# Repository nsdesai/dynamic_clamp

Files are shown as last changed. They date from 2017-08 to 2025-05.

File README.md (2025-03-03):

# dynamic_clamp
A fast, microcontroller-based dynamic clamp system

The system was introduced in this paper: Niraj S. Desai, Richard Gray, and Daniel Johnston. A dynamic clamp on every rig. eNeuro (DOI:10.1523/ENEURO.0250-17.2017).

The website https://optogeneticsandneuralengineeringcore.gitlab.io/dynamicclampsite/ includes detailed instructions on how to assemble and use the system. It includes descriptions of recent updates.

This site (github.com) houses most of the associated software (Arduino, Processing, Matlab).

The original project was built on a breadboard and used Arduino/Processing software. Some alternatives you might consider:

(1) Leo and Manuel Covarrubias have further developed the design and created a different printed circuit board (PCB) version. Called Open Dynamic Clamp (ODC) it includes numerous improvements that will, hopefully, "future proof" the project. Information about ODC is contained here: https://github.com/nsdesai/dynamic_clamp/tree/master/open-dynamic-clamp.

(2) Aditya Asopa (https://github.com/AdityaAsopa) has designed a PCB version that can be used in place of the breadboard. It includes some nice additional features, including a toggle switch to bypass the dynamic clamp circuitry (useful if one wants to just work in current clamp). The design files are in the Circuit_and_PCB folder, while a setup and calibration manual is in the Setup_and_Calibration folder.

(3) Christian Rickert has written alternative software (dyClamp and pyClamp) with extended functionality, including a Python-based control GUI. His software is described at https://dynamicclamp.com/python-alternative/ and is available through his Github account https://github.com/christianrickert.

(4) Kyle Wedgwood has written a Matlab controller that would replace the Processing sketch included here. It allows more flexibility in specifying which conductances to control, and is available through his Github account https://github.com/kyle-wedgwood/DynamicClampController.

Please direct any questions or comments about this Github site or the dynamic clamp project generally to Niraj S. Desai at niraj.s.desai@gmail.com.

******************************************************************************************************************************************
Permission is hereby granted, free of charge, to any person obtaining a copy of this software and associated documentation files (the "Software"), to deal in the Software without restriction, including without limitation the rights to use, copy, modify, merge, publish, distribute, sublicense, and/or sell copies of the Software, and to permit persons to whom the Software is furnished to do so, subject to the following conditions:

The above copyright notice and this permission notice shall be included in all copies or substantial portions of the Software.

THE SOFTWARE IS PROVIDED "AS IS", WITHOUT WARRANTY OF ANY KIND, EXPRESS OR IMPLIED, INCLUDING BUT NOT LIMITED TO THE WARRANTIES OF MERCHANTABILITY, FITNESS FOR A PARTICULAR PURPOSE AND NONINFRINGEMENT. IN NO EVENT SHALL THE AUTHORS OR COPYRIGHT HOLDERS BE LIABLE FOR ANY CLAIM, DAMAGES OR OTHER LIABILITY, WHETHER IN AN ACTION OF CONTRACT, TORT OR OTHERWISE, ARISING FROM, OUT OF OR IN CONNECTION WITH THE SOFTWARE OR THE USE OR OTHER DEALINGS IN THE SOFTWARE.

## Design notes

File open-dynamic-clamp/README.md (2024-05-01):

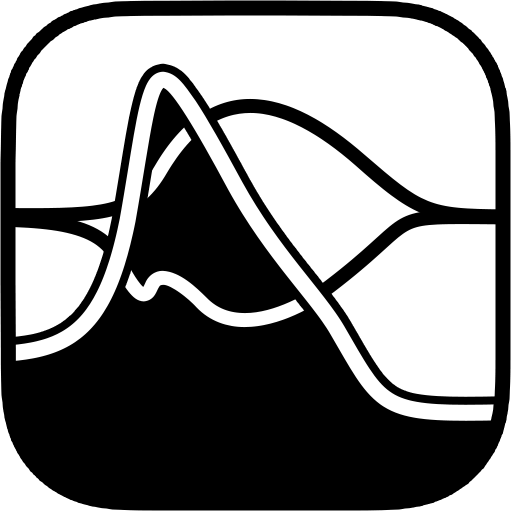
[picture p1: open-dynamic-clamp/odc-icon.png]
#  Open Dynamic Clamp

The Open Dynamic Clamp project (abbreviated ODC) is an extension of the the work by [Niraj Desai](https://github.com/nsdesai), [Aditya Asopa](https://github.com/AdityaAsopa), and other contributors.
It aims to provide consistent, incremental progress on dynamic clamp hardware and software for the scientific community by documenting manufacturable designs that
lower the barrier for use by any interested researchers.

- Hardware is licensed under [CC BY 4.0](https://creativecommons.org/licenses/by/4.0/) terms.



# Versions

- [ODC 1.0](odc-1.0/prototype.md)
  - Hand-built prototype design
- [ODC 1.2](odc-1.2/README.md)
  - PCB hardware and 3D Printed Enclosure

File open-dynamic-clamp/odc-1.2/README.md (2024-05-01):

# Open Dynamic Clamp 1.2

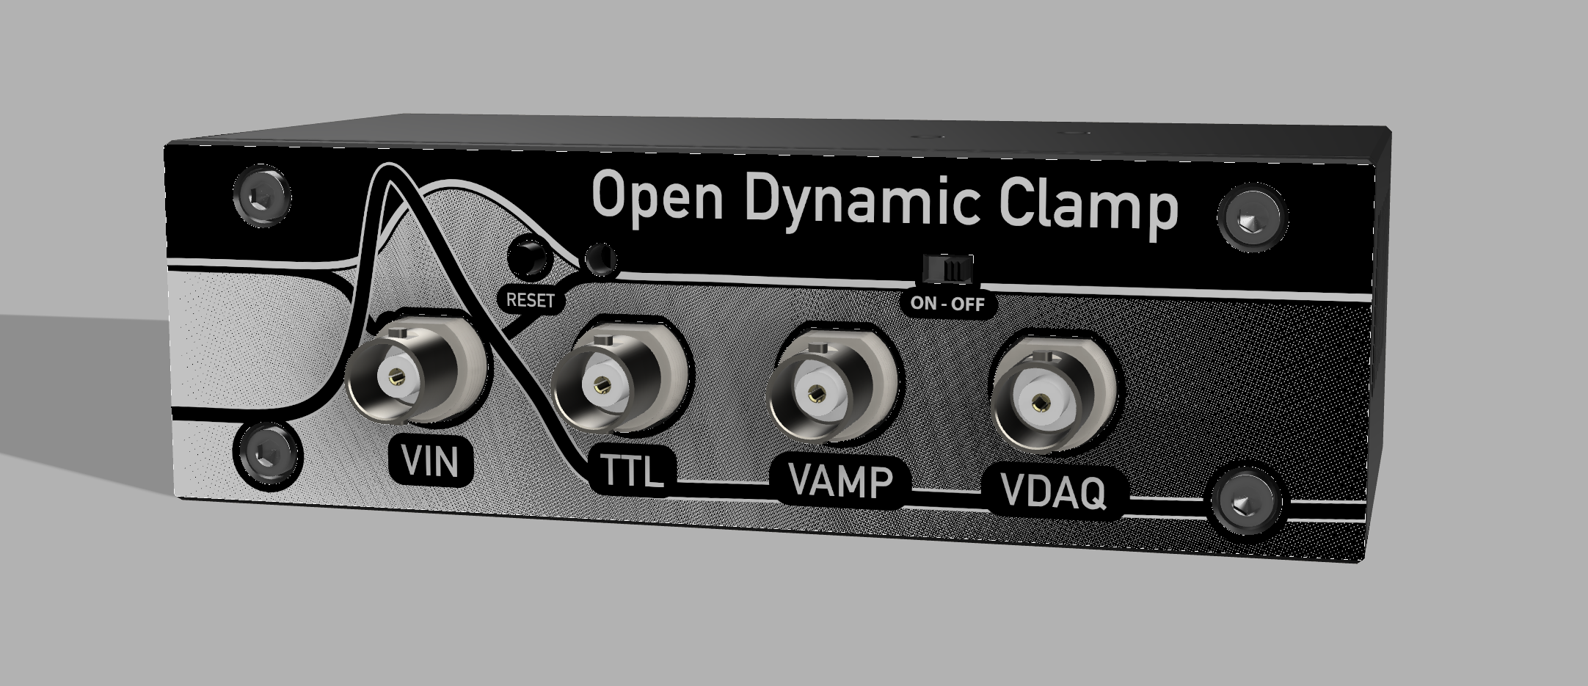
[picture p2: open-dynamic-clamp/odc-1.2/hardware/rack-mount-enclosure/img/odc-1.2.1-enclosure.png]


### Notable Features
- 100% compatible with existing Arduino firmware
- Using the [Adafruit ItsyBitsy M4](https://learn.adafruit.com/introducing-adafruit-itsybitsy-m4) microcontroller (SAMD51 MCU)
- Simplified power circuitry
  - USB used to source all power, no additional DC input required
  - 3.3V sourced from the ItsyBitsy's built-in voltage regulator
  - Op amp dual rail provided by 5V to +/-12V DC-to-DC module
- TLE2142 Op amp replaces LM358 for improved signal quality
- Trim potentiometers for Op amp gain and offset adjustment
- Expansion port for additional ADC inputs
- Tag-Connect Plug-of-Nails debugging header
- Fully specified BOM with the highest quality components

### Project Files

- [Hardware PCB Guide](./hardware/README.md)
  - KiCad Project
- [3D Printed Enclosure Guide](./hardware/rack-mount-enclosure/README.md)
  - STL Files
  - Faceplate Graphic

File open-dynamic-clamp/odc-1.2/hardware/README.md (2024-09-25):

# Open Dynamic Clamp 1.2 Hardware

This documentation describes circuit schematics for the ODC 1.2 hardware iteration.
This design is based on the work of [Aditya Asopa's updated schematic](../../../Setup%20and%20Calibration%20Manual%20for%20ver2.0/Setup%20Manual.pdf).

This hardware design is licensed under [CC BY 4.0](https://creativecommons.org/licenses/by/4.0/).

- Table of Contents
  - [User Guide](#user-guide)
  - [PCB Assembly Notes](#pcb-assembly-notes)
  - [Calibration Notes](#calibration-notes)
  - [Firmware Notes](#firmware-notes)

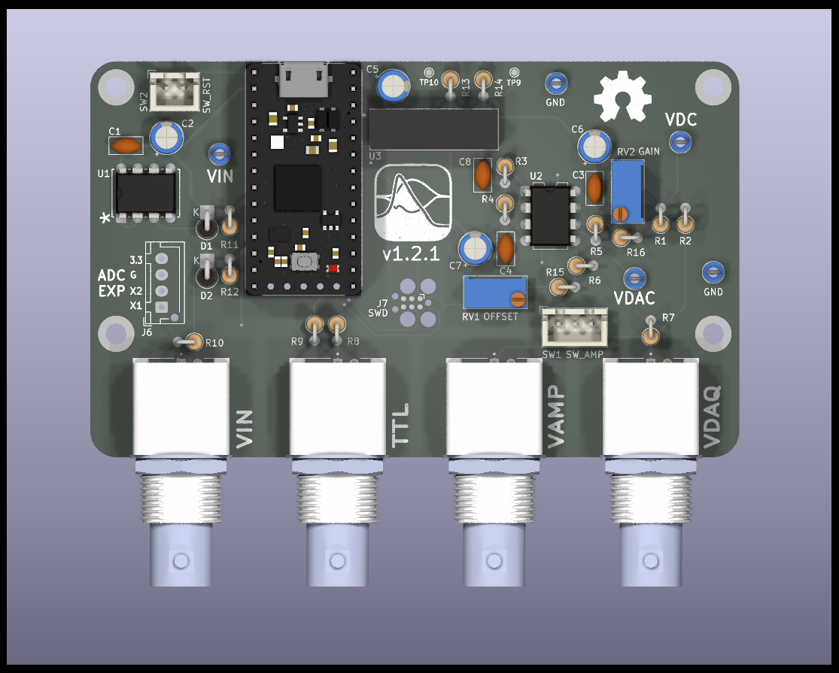
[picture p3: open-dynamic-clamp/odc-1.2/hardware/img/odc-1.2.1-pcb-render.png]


# User Guide

The design may be built successfully on a breadboard or ordered as a PCB.

- [KiCad Project](./odc-1.2)
  - [Schematic](./odc-1.2/pdf/odc-1.2.pdf)
  - [BOM](./odc-1.2/bom/odc-1.2-bom.csv)
  - [Fabrication](./odc-1.2/gerber/README.md)
- The design has been created with 100x amplification in mind
- Choose resistors with a low tolerance to avoid calibration problems (the BOM specifies high quality resistors)
  - 0.1% resistors are highly recommended but 1% resistors may be acceptable with calibration.
  - [DigiKey importable cart CSV](odc-1.2/bom/odc-1.2-digikey-cart.csv) is available with all components pre-configured.
- Double check connections before powering the circuit from the ItsyBitsy M4 module.
  - A short circuit has the risk of burning out the microcontroller module's on-board regulator.
  - Testing with the ItsyBitsy board connected by jumper wires is encouraged.
- The ADC EXP expansion port is NOT protected from over-voltage. The ItsyBitsy M4 will be damaged by voltages outside the 0-3.3V range.
- The trim potentiometers should be tuned during calibration.
- If mounting in a 3d printed enclosure the two switches should be extended from the PCB with short wire leads. These extension wires may be soldered directly to the pcb or made detachable using JST XH connectors.

# PCB Assembly Notes

An [interactive BOM](odc-1.2/bom/ibom.html) is available to help with assembly (open the html file in any browser).

- Take careful note of capacitor polarity. 
  - Capacitor C7 is on a negative rail.
- The PCB has a large ground plane that soaks up heat making soldering ground connections tricky.
  - For each component solder the signal or power connection first to hold it in place before carefully soldering the ground.
  - Use plenty of flux. This will significantly improve the solders ability to flow.
    - ChipQuick No-Clean Tack Flux Syringe is highly recommended.
  - Use caution around sensitive components or plastic connectors that might melt.
- Diodes with a "K" on the board are "cathode up" which means the body of the diode lines up with the circular outline and the white stripe is pointing up.
- Use of standard height headers/pins are assumed for the Adafruit ItsyBitsy M4.
  - If you use different height headers the board may not line up with the enclosure opening
  - The 5 bottom middle pins of the ItsyBitsy M4 are only required if using SWD debugging.
- The external reset switch (SW2) is optional. The reset button on the ItsyBitsy M4 board serves the same function.
- The selector switch footprint (SW1) fits any SPDT switch or header with a 2.54mm lead spacing.
- The named test points do not need to be populated but are a convenience for clipping oscilloscope leads calibration/validation.

# Calibration Notes

A validation and calibration process is described in the [Setup Manual](../../../Setup%20and%20Calibration%20Manual%20for%20ver2.0/Setup%20Manual.pdf) by Aditya Asopa.

- Trim potentiometers for `RV1` and `RV2` will aid in setting the gain and offset. There are 2 options.
  1. You may adjust them to produce a symmetrical +/- 3.3V at `VAMP` using [this arduino sketch](./scripts/trim-gain-and-offset/trim-gain-and-offset.ino) and an oscilloscope (Must have `VDAQ` at 0V).
  2. You may adjust them to produce the exact same output as described in validation Table 2 (page 13) and Table 3 (page 15).
- To provide the required `5V` and `3.3V` power rails during initial validation you may:
  - provide the correct voltages to the correct header pins with the ItsyBitsy completely removed.
  - Power the ItsyBitsy with a USB cable and connect the `USB`, `3V` and `G` pins to the PCB headers with extension jumpers such that all other pins remain disconnected.
  - Power the ItsyBitsy with a USB cable and socket it into the PCB headers but double-click the reset button to put it into programming mode (this prevents any output voltage on the DAC pin due to any currently loaded firmware). You will see the red LED next to the reset button pulse slowly.
- Calibration to derive the slope and intercept values in table 13 (page 31) required by the firmware may be done by any of the described methods (Direct page 20, Model Cell + Processing page 23, Model Cell + Arduino page 29)
  - If you have hardware conforming to the 1.2.1 design with the trim potentiometers set to produce +/- 3.3V, then these precalculated values should work
    - input slope: `4.9756`
    - input intercept: `-10087.453`
    - output slope: `-624.3895`
    - output intercept: `2108.4`
  - See [example calculations spreadsheet](https://docs.google.com/spreadsheets/d/1fMq_oq5LJLbKDHQDHSRb5kDalZ01myzjR7bMcWg4iwA) for details on deriving calibration values

# Firmware Notes

This hardware revision (ODC 1.2) is 100% compatible with the original
[dynamic_clamp](../../../dynamic_clamp) Arduino firmware.

Adafruit provides an extensive Arduino setup guide which is a prerequisite for loading the firmware.
1. [Setup the Arduino IDE](https://learn.adafruit.com/introducing-adafruit-itsybitsy-m4/setup)
2. [Install Adafruit board support](https://learn.adafruit.com/introducing-adafruit-itsybitsy-m4/using-with-arduino-ide)

> [!IMPORTANT]
> 
> If you are having problems uploading firmware in the Arduino IDE you may need
> to put the device into "Boot Mode" by quickly double-clicking the reset button.
> This is useful if you can't see the device serial port in the Arduino IDE
> board selection window. This should allow you to upload new firmware in cases 
> were bad firmware is crashing the microcontroller.

Additional useful information on the ItsyBitsy M4 board:
- [General board overview](https://learn.adafruit.com/introducing-adafruit-itsybitsy-m4/overview)
- [Board pin descriptions](https://learn.adafruit.com/introducing-adafruit-itsybitsy-m4/pinouts)

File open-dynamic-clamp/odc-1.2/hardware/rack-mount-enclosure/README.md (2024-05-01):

# 3D Printed Enclosure Guide

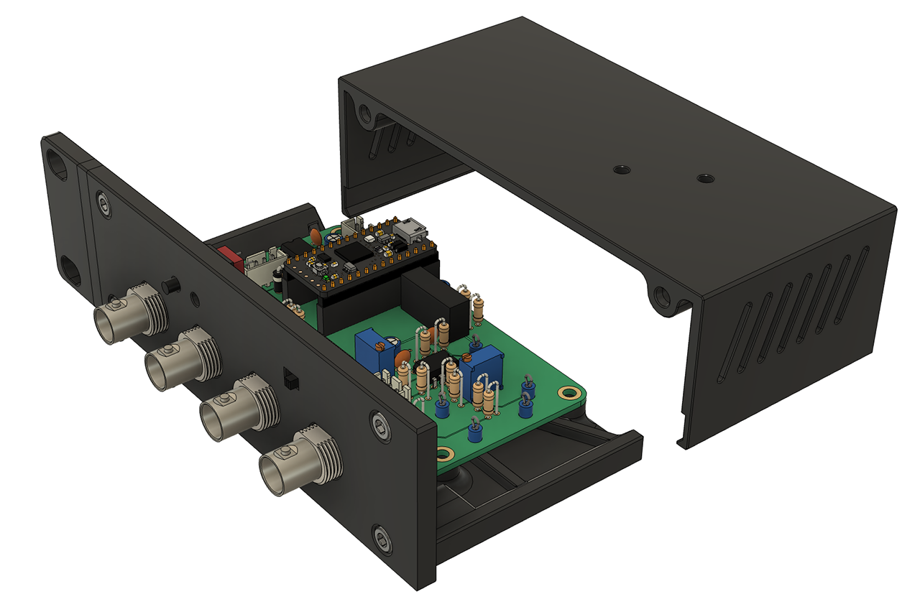
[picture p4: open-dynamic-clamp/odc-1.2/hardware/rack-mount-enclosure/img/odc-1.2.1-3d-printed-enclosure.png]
enclosure-render


For printing a rack mount or desktop enclosure the following files are used.
There are various options for face-plates.

#### STL Files
- Faceplate options (choose one)
  - faceplate-ears-left.stl (rack mount holes on left)
  - faceplate-ears-right.stl (rack mount holes on right)
  - faceplate-no-ears.stl (desktop use, no mounting holes)
- pcb_sled.stl (pcb mounting bracket)
- cover.stl (enclosure cover)

### Fusion 360 Files
A Fusion 360 project (.f3z) is provided for anyone looking to make modifications to the design.

#### Hardware
- 8 M3 heat-set inserts
- 8 M3 6mm bolts

## 3D Printing Notes

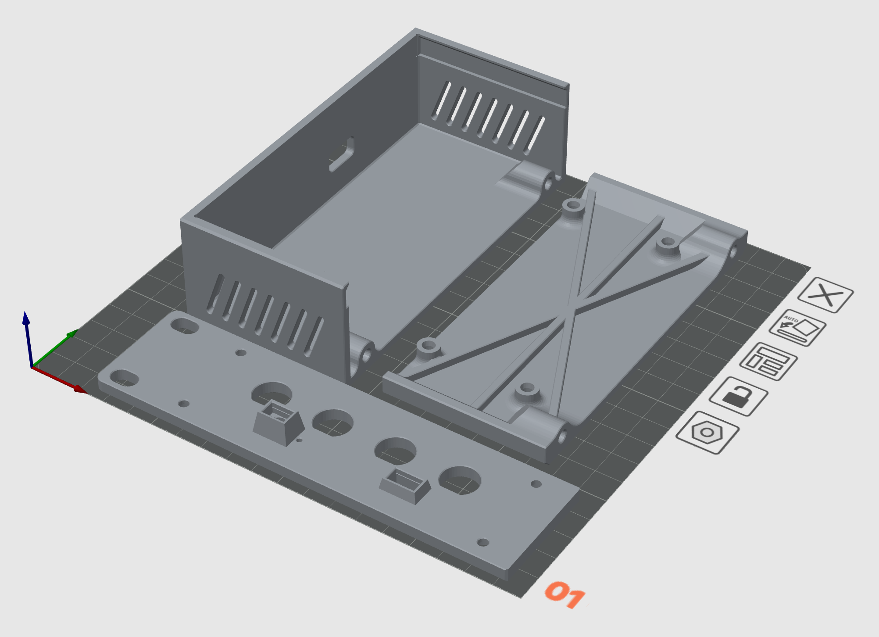
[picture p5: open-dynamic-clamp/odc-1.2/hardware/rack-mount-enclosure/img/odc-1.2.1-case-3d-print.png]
3d-print-build-plate


- All parts will fit together on a 200x200 build plate
- Slicer recommendations
  - PLA filament
  - 0.3 layer height
  - No supports or supports only for usb cable opening

## Faceplate Graphic Notes

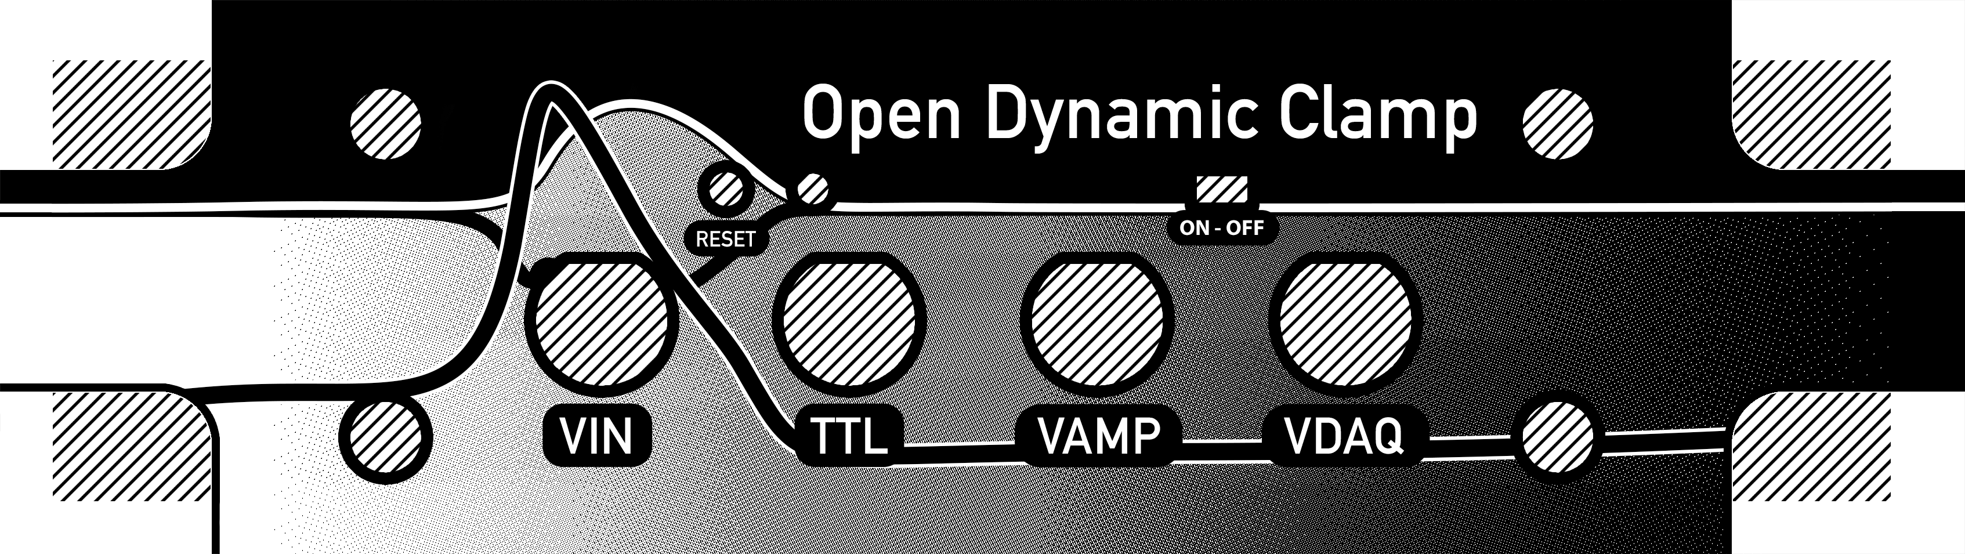
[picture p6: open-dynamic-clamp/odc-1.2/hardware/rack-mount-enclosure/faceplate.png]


Graphic is designed to be printed on a B&W laser printer using Avery 5526 shipping labels.

- Cut out the cross-hatched areas carefully with a new exacto blade.
- Some overlap on edges to be cut has been designed into the graphic so that cuts always happen on black which blends with black 3d printing filament.

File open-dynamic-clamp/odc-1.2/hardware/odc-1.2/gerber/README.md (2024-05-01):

# Fabrication Notes

The gerber files provided are all that's needed for fabrication by a 3rd party PCB manufacturer.

Follow the manufacturers instructions to upload the files from the `odc-1.2/gerber` directory.

The fabrication options conform to most PCB fab capabilities.
There are no special manufacturing requirements.

- 100x61mm size
- 2 layer board
- FR-4
  - 1.6mm
  - TG 130-140 or TG 150-160
- 6/6mil track width/spacing
- 0.3mm min hole size
- 1oz CU

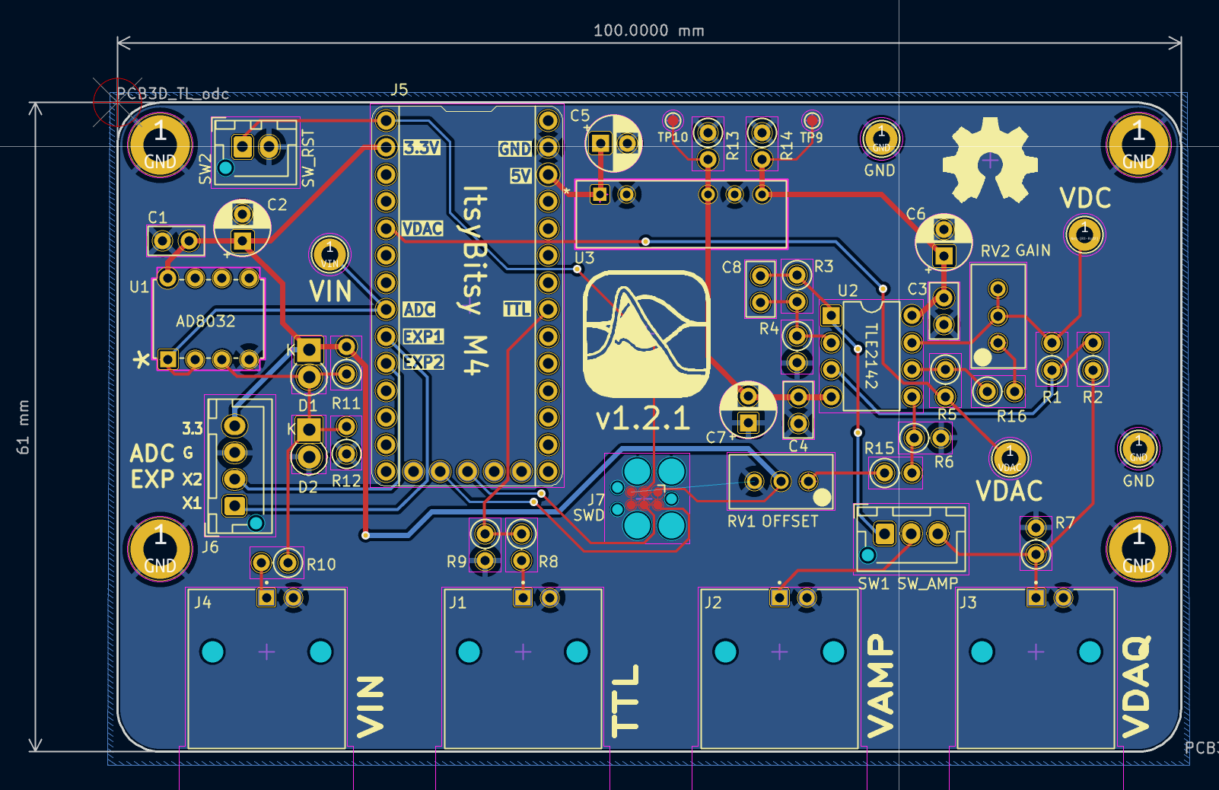
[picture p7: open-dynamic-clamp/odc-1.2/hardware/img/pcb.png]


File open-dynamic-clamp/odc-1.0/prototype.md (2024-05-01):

# Prototype Notes

A single prototype version (considered ODC 1.0) was constructed on proto-board and hand soldered with jumper wires. 
This revision was used by the [Covarrubias Lab, Dep. of Neuroscience at Thomas Jefferson University](https://research.jefferson.edu/labs/researcher/covarrubias-laboratory.html).

### Differences to ODC 1.2

- The prototype was constructed with an LM358 OpAmp for the output signal. Version 1.2 recommends the pin-compatible TLE2142 OpAmp an included an additional filtering capacitor to reduce ringing artifacts.
- The prototype used an external 3.3V regulator instead of the ItsyBitsy's onboard 3.3V regulator.
- Additional bypass capacitors for the voltage rails are not present in the prototype.
- The tolerance of resistor components (5-10%) on the prototype necessitated additional calibration.
- The configuration of the trim potentiometers to adjust output signal offset and gain has been changed to improve stability from thermal variance.
- Proto-board construction (this has not shown a measurable difference compared to the
PCB version).
- Additional pins from the ItsyBitsy are exposed on user accessible headers for ADC inputs and SWD Debugging.
- The BNC ports are not in the same physical order (irrelevant)

### Build Images
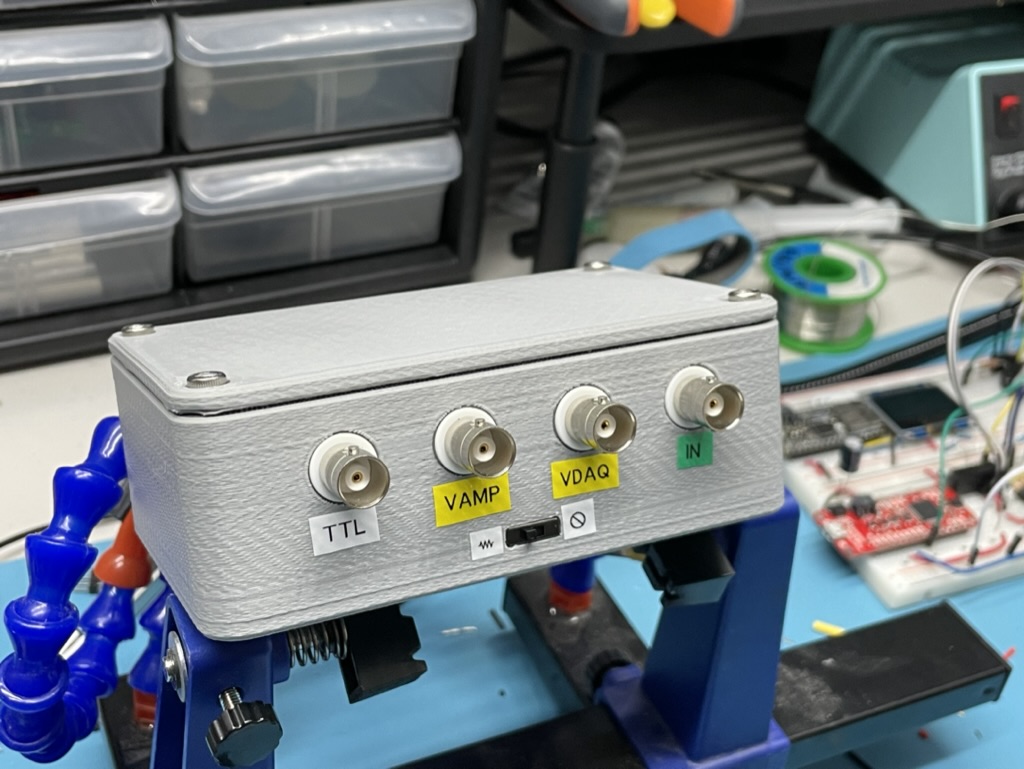
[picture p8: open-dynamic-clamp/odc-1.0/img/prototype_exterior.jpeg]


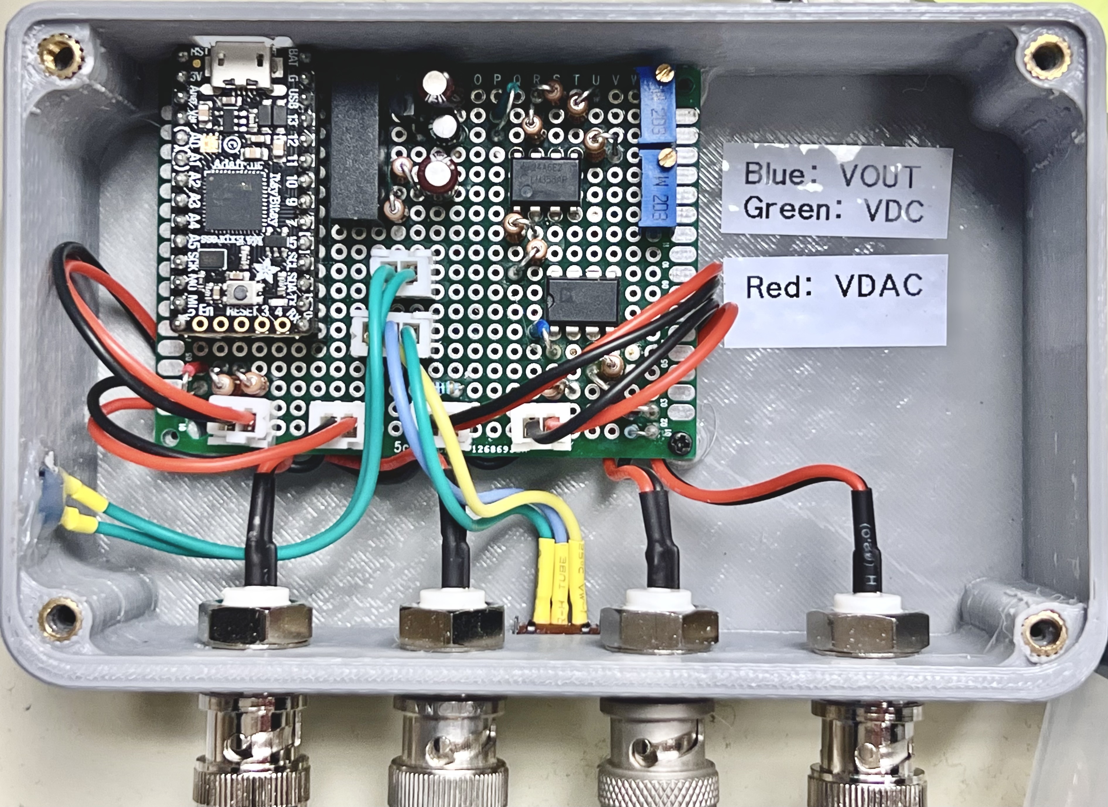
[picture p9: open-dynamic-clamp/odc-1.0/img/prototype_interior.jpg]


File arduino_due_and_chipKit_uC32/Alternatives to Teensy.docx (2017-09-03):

Alternatives to Teensy

We built the dynamic clamp system around the Teensy 3.6 microcontroller because, compared to alternatives of its class and price point, it is faster and has more memory. However, it is important to note that other microcontrollers could be used in its place. In particular, microcontrollers that can be programmed using the Arduino integrated development environment (IDE) require only small modifications to the code. There are many microcontrollers like this because Arduino has emerged as a standard in the community.

To demonstrate this point, we describe in this document how to use an Arduino Due or a chipKit uC32 in place of the Teensy 3.6. Neither is the equal of the Teensy 3.6 in speed or memory, but both are plausible alternatives.

I. Arduino Due

The Arduino line of microcontrollers includes many products (www.arduino.cc). At this writing (08/26/17), the product best suited to the dynamic clamp technique is the Arduino Due (clock speed 84 MHz, 512 kB flash memory, 92 kB SRAM memory). It includes 12 ADC inputs and 2 DAC outputs.

In the folder dynamic_clamp_arduino_due, we have modified the dynamic clamp code to work with the Arduino Due.

Main file. The main file differs from that of the Teensy main file in only two ways. (1) The pin connections have different names. The first DAC output of the Due is called “DAC0” whereas that of the Teensy is “A21”. The EPSC trigger pin we use for the Due is number 13 rather than number 2. (2) To keep track of time, we use the built-in Arduino functions millis() and micros() rather than the data types elapsedMillis and elapsedMicros. The latter types are also available for the Due but using them requires installing a separate library. Of course, this is simple to do but we chose instead to illustrate how to use millis() and micros() in place of the elapsed time data types; both methods work with the Teensy 3.6.

Tabbed (conductance) files. The Teensy has a floating point unit (FPU). To instruct the compiler to use the FPU, one uses special functions that end in the letter f in place of standard functions. One uses expf() to calculate an exponential rather than exp(); one uses sinf() to calculate the sine rather than sin(). The Due does not have an FPU. To make the code compatible with the Due, we simply removed the letter f – that is, we replaced the special FPU functions with the standard functions.

One other thing to keep in mind when using the Due: although the DAC outputs are nominally 3.3 V, they do not cover the full range between 0 V and 3.3 V. Instead they only cover the range 0.55 V to 2.75 V. The output calibration parameters (slope and intercept) will therefore be different from what one would have calculated using a Teensy.

II. chipKit uC32

chipKit is a line of microcontrollers based on Microchip Technology’s PIC32 microcontroller chip (chipkit.net). Even though it is not an Arduino product, it can still be programmed using the Arduino IDE.

One nice thing about the chipKit uC32 is that there is an add-on called Analog Shield (http://bit.ly/2wehEpp) available for it. This add-on allows the uC32 to read and write voltages between -5 V and +5 V directly. This means that users will not need to build the differential amplifier parts of the system (parts 2 and 4 of Fig. 1B of the main text). Of course, this convenience comes at a price ($50 as of this writing).

In the folder dynamic_clamp_chipKit_uC32, we have modified the dynamic clamp code to work with the chipKit uC32.

Main file. In addition to the two changes that apply to the Arduino Due (pin connections with different names; using millis() and micros() instead of the elapsed time data types), the uC32 main file must be modified in other respects to take advantage of the Analog Shield. (1) At the top of the file, we include two necessary libraries (analogShield.h and SPI.h). (2) The functions analogRead() and analogWrite() are replaced by analog.read() and analog.write(). (3) The ADC inputs and DAC outputs of the Analog Shield are 16 bit rather than 12 bit. So the calibration numbers are all different from those for the Teensy and the output is constrained to be less than 65536 (= 2^16) rather than less than 4096 (= 2^12).

Tabbed (conductance) files. As in the Arduino Due case, we must remove the letter f because the uC32 lacks an FPU.

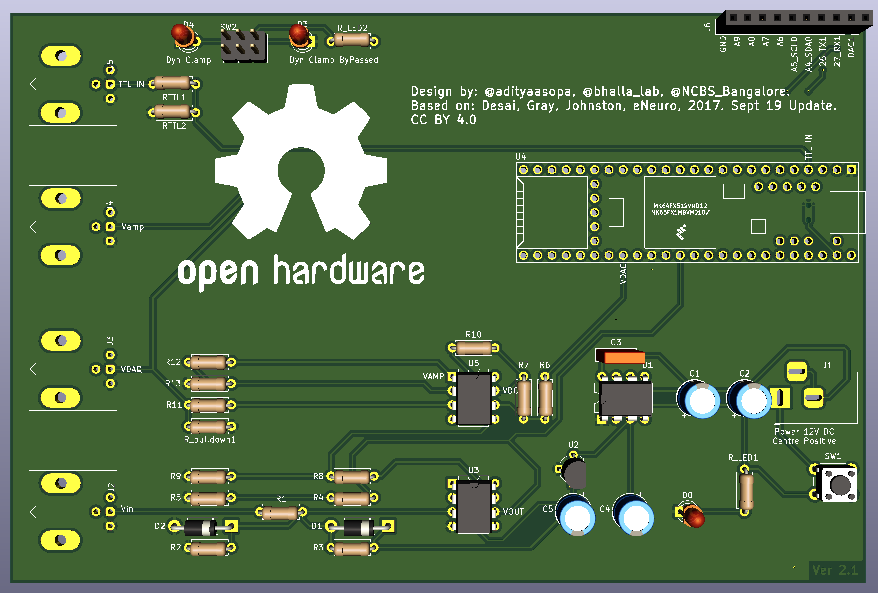
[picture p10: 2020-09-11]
Circuit_and_PCB/teenDynClamp_V02.png

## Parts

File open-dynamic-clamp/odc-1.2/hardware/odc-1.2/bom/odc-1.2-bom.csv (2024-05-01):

Reference | Value | Qty | Datasheet | Footprint | DNP
C1,C3,C4 | 0.1uF | 3 | https://www.digikey.com/en/products/detail/kemet/C320C104K5R5TA7317/6562447 | Capacitor_THT:C_Disc_D5.0mm_W2.5mm_P2.50mm
C2,C5,C6,C7 | 10uF/35V | 4 | https://www.digikey.com/en/products/detail/kemet/ESS106M035AC2EA/9448275 | Capacitor_THT:CP_Radial_D5.0mm_P2.50mm
C8 | 6.8pF | 1 | https://www.digikey.com/en/products/detail/kemet/C315C689D2G5TA/3726120 | Capacitor_THT:C_Disc_D5.0mm_W2.5mm_P2.50mm
D1,D2 | 1N5817 | 2 | https://www.digikey.com/en/products/detail/stmicroelectronics/1N5817/770963 | Diode_THT:D_DO-41_SOD81_P2.54mm_Vertical_KathodeUp
H1,H2,H3,H4,J6,TP9,TP10 | -- mixed values -- | 7 | ~ | -- mixed values -- | DNP
J1,J2,J3,J4 | Conn_Coaxial | 4 | https://www.digikey.com/en/products/detail/te-connectivity-linx/CONBNC002/16013841 | lib_fp:LINX_CONBNC002
J5 | Adafruit_ItsyBitsy_M4 | 1 | https://www.digikey.com/en/products/detail/adafruit-industries-llc/3800/9448047 | lib_fp:Adafruit_ItsyBitsy_M4
R1,R2,R3,R4,R10 | 10K | 5 | https://www.digikey.com/en/products/detail/yageo/MFP-25BRD52-10K/2058797 | Resistor_THT:R_Axial_DIN0207_L6.3mm_D2.5mm_P2.54mm_Vertical
R5,R6,R12 | 4.7K | 3 | https://www.digikey.com/en/products/detail/yageo/MFP-25BRD52-4K7/2058823 | Resistor_THT:R_Axial_DIN0207_L6.3mm_D2.5mm_P2.54mm_Vertical
R7 | 1M | 1 | https://www.digikey.com/en/products/detail/yageo/MFR-25FTE52-1M/9139874 | Resistor_THT:R_Axial_DIN0207_L6.3mm_D2.5mm_P2.54mm_Vertical
R8,R9 | 1K | 2 | https://www.digikey.com/en/products/detail/yageo/MFP-25BRD52-1K/2058804 | Resistor_THT:R_Axial_DIN0207_L6.3mm_D2.5mm_P2.54mm_Vertical
R11,R13,R14 | 3.3K | 3 | https://www.digikey.com/en/products/detail/yageo/MFP-25BRD52-3K3/2058819 | Resistor_THT:R_Axial_DIN0207_L6.3mm_D2.5mm_P2.54mm_Vertical
R15,R16 | 7.5K | 2 | https://www.digikey.com/en/products/detail/yageo/MFP-25BRD52-7K5/2058831 | Resistor_THT:R_Axial_DIN0207_L6.3mm_D2.5mm_P2.54mm_Vertical
RV1,RV2 | 5K | 2 | https://www.digikey.com/en/products/detail/bourns-inc/3296W-1-502LF/1088058 | Potentiometer_THT:Potentiometer_Bourns_3296W_Vertical
SW1 | SW_AMP | 1 | https://www.digikey.com/en/products/detail/nidec-components-corporation/AS1D-2M-10-Z/1792118 | Connector_JST:JST_XH_B3B-XH-AM_1x03_P2.50mm_Vertical
SW2 | SW_RST | 1 | https://www.digikey.com/en/products/detail/cit-relay-and-switch/BSP10TCQ/12503376 | Connector_JST:JST_XH_B2B-XH-AM_1x02_P2.50mm_Vertical
TP1,TP4,TP6,TP7,TP11 | -- mixed values -- | 5 | https://www.digikey.com/en/products/detail/keystone-electronics/5012/255334 | TestPoint:TestPoint_Loop_D2.60mm_Drill1.6mm_Beaded
U1 | AD8032ANZ | 1 | https://www.digikey.com/en/products/detail/analog-devices-inc/AD8032ANZ/751127 | lib_fp:N_8_ADI
U2 | TLE2142 | 1 | https://www.digikey.com/en/products/detail/texas-instruments/TLE2142IP/380919 | Package_DIP:DIP-8_W7.62mm
U3 | TMV_0512D | 1 | https://www.digikey.com/en/products/detail/traco-power/TMV-0512D/9383521 | lib_fp:TMV_5_12_DUAL_TRP

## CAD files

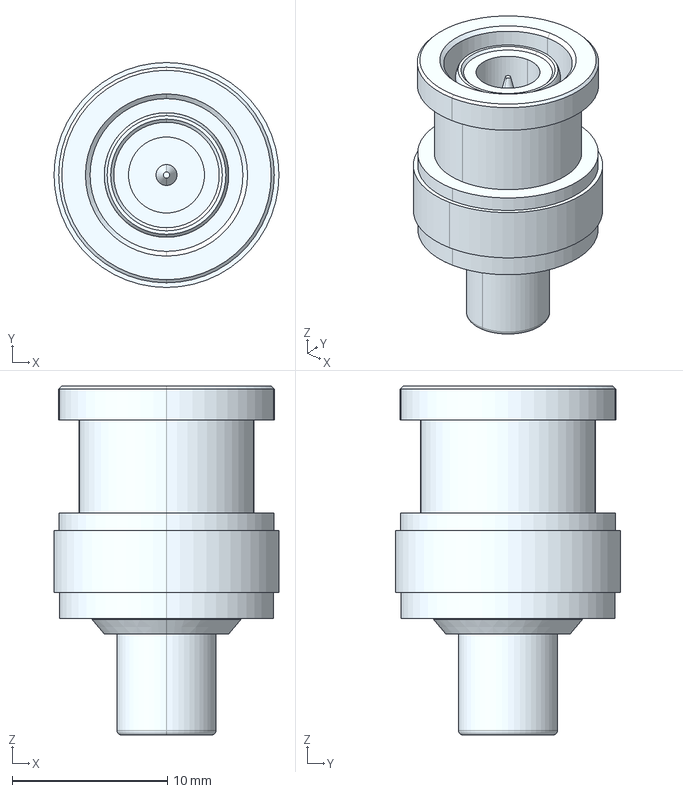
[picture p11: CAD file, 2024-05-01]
open-dynamic-clamp/odc-1.2/hardware/odc-1.2/3d_models/c-1-1337463-0-d-3d.stp
14.5 x 14.5 x 22.5 mm

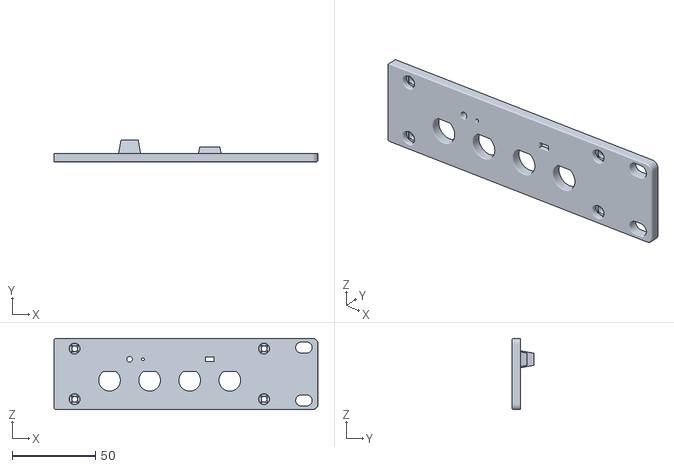
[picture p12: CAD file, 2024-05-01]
open-dynamic-clamp/odc-1.2/hardware/rack-mount-enclosure/stl/faceplate-ears-right.stl
158.9 x 13.0 x 43.0

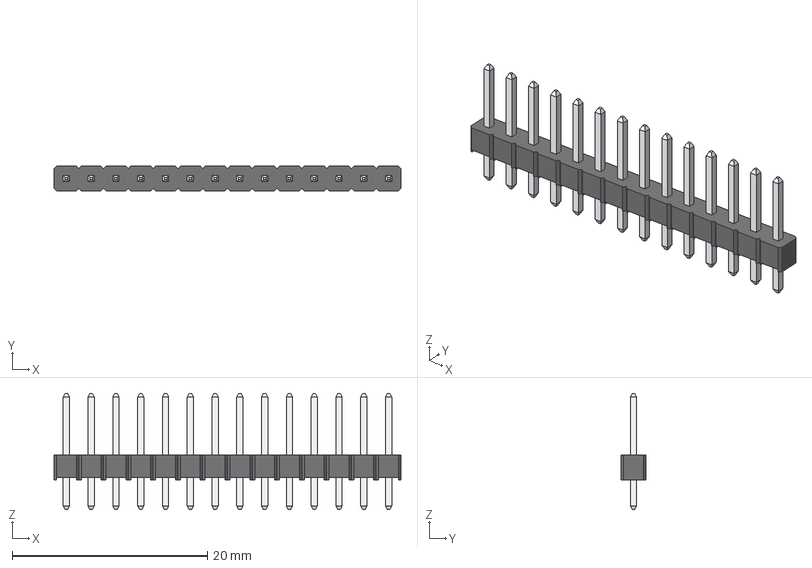
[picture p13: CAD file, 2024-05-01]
open-dynamic-clamp/odc-1.2/hardware/odc-1.2/3d_models/14-Pin Header - Male - 2.54mm.step
35.6 x 2.54 x 11.9 mm

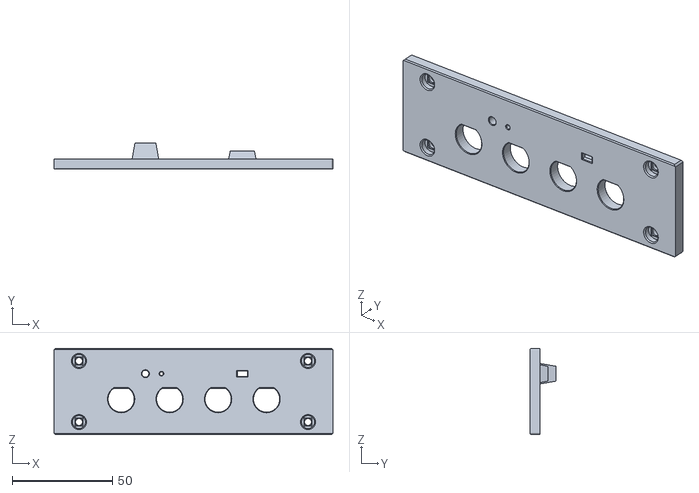
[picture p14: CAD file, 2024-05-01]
open-dynamic-clamp/odc-1.2/hardware/rack-mount-enclosure/stl/faceplate-no-ears.stl
138.9 x 13.0 x 43.0

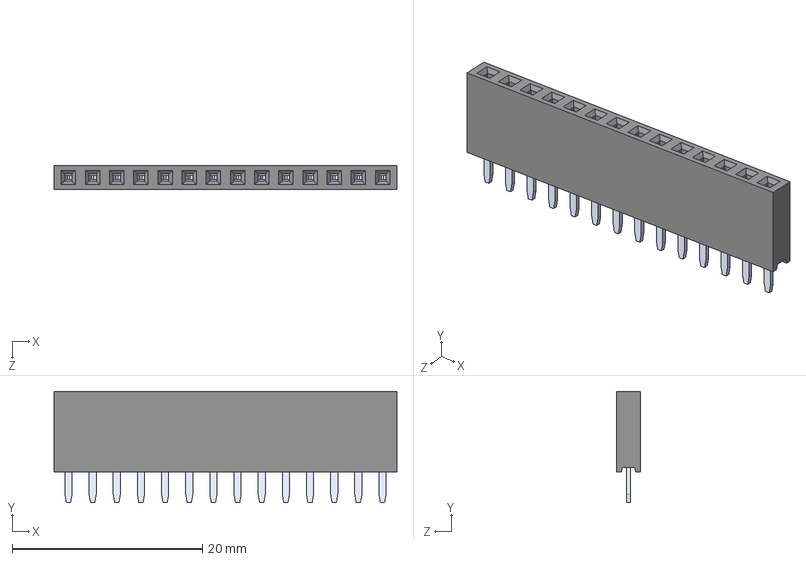
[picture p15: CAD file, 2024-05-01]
open-dynamic-clamp/odc-1.2/hardware/odc-1.2/3d_models/PPTC141LFBN-RC.STEP
36.1 x 11.7 x 2.54 mm

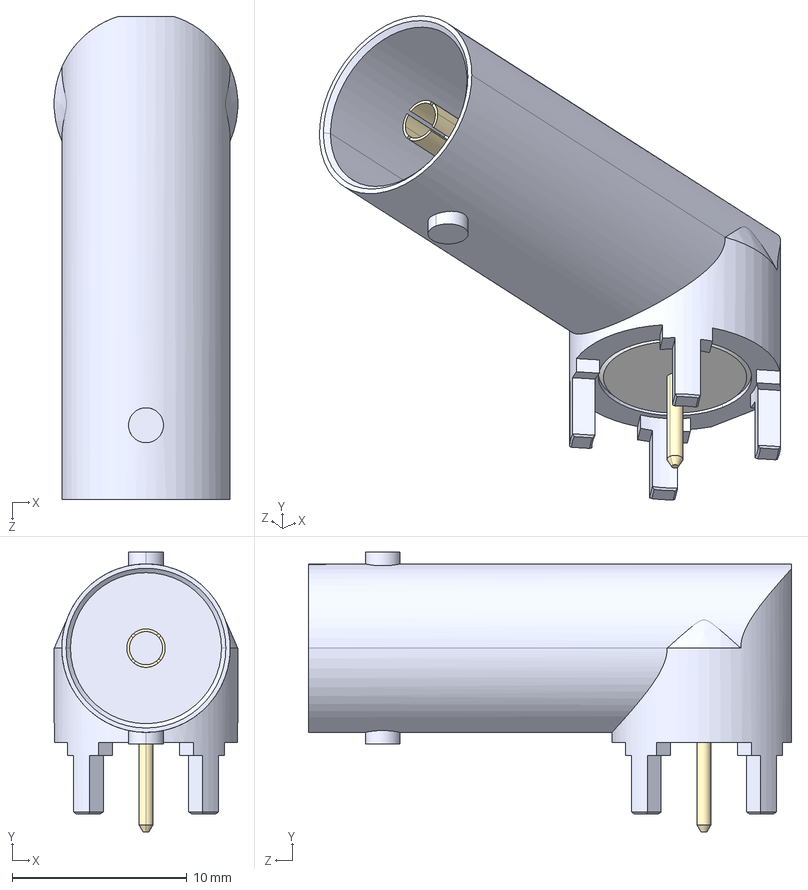
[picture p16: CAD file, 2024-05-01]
open-dynamic-clamp/odc-1.2/hardware/odc-1.2/3d_models/molex-0731711640.step
10.5 x 16.0 x 27.6 mm

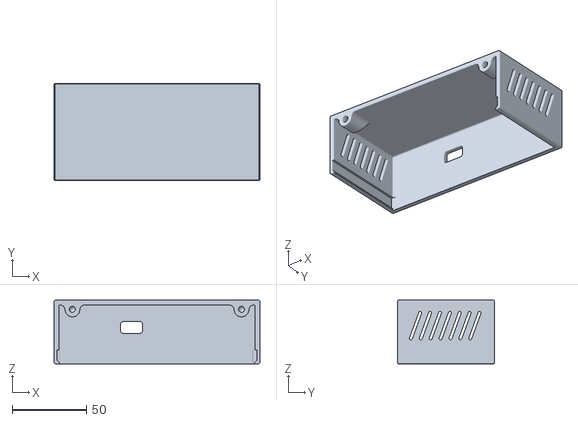
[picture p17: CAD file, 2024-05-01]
open-dynamic-clamp/odc-1.2/hardware/rack-mount-enclosure/stl/cover.stl
138.9 x 65.3 x 43.0

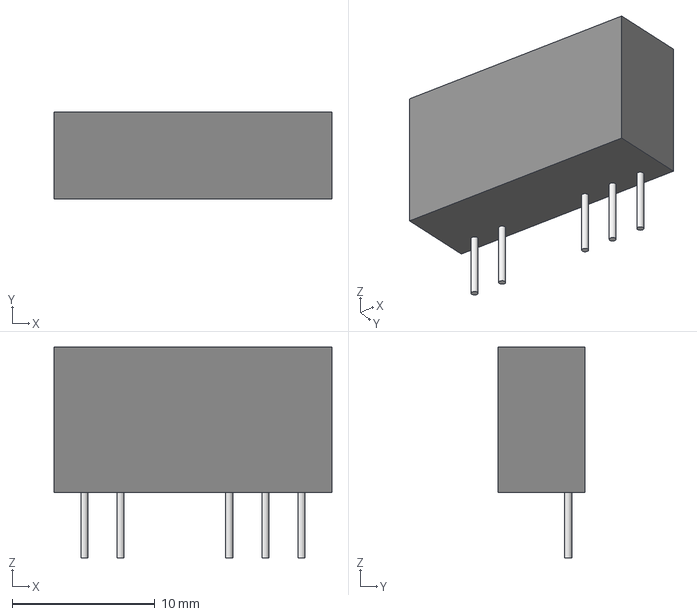
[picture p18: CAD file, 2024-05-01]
open-dynamic-clamp/odc-1.2/hardware/odc-1.2/3d_models/TMV_512_DUAL_TRP.step
19.5 x 6.10 x 14.8 mm

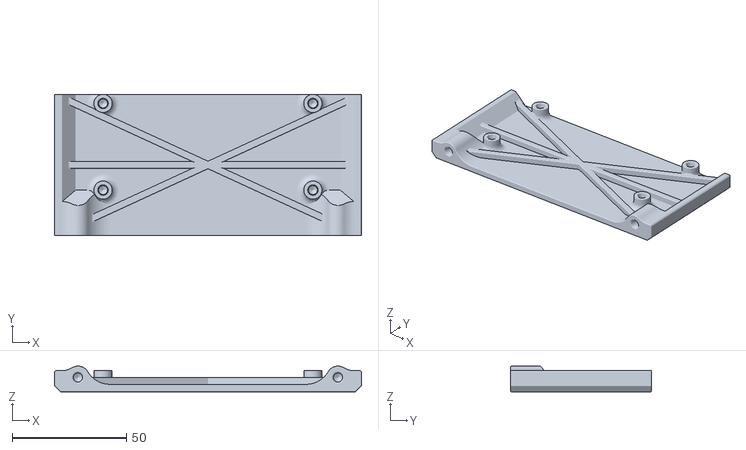
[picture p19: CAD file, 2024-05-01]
open-dynamic-clamp/odc-1.2/hardware/rack-mount-enclosure/stl/pcb_sled.stl
134.6 x 62.0 x 11.3

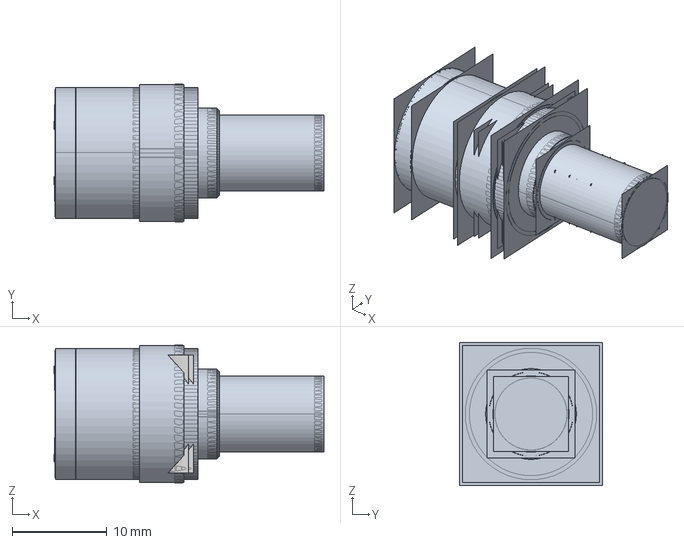
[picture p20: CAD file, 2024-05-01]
open-dynamic-clamp/odc-1.2/hardware/odc-1.2/3d_models/000-46650-75rfx.igs
28.4 x 15.1 x 15.1 mm

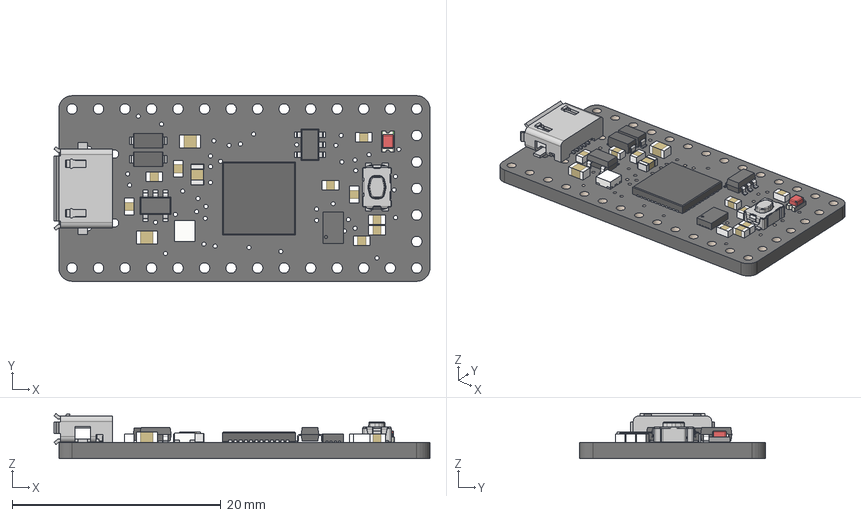
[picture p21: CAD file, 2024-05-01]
open-dynamic-clamp/odc-1.2/hardware/odc-1.2/3d_models/3800-ItsyBitsy-M4.step
36.0 x 17.8 x 4.34 mm
Board
10µF x 2
100k x 6
RED
SPST_TACT-KMR2
microUSB
AP2112K-3.3
74HCT1G125DBV
MBR120 x 2
AP102-2020
GD25x16
ATSAMD51G_TQFN48
10uF
1uF x 3

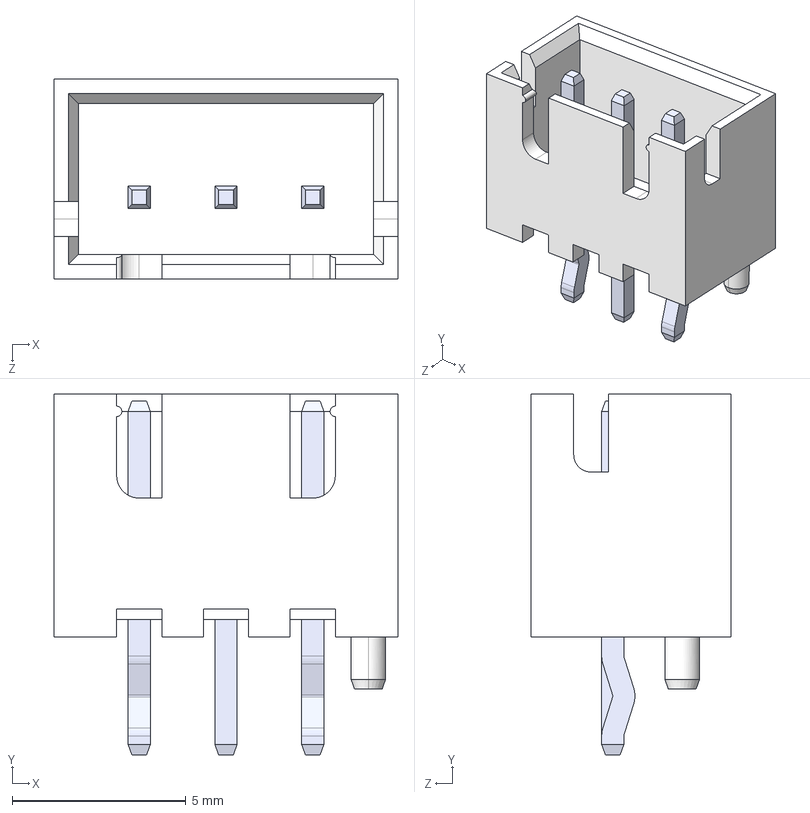
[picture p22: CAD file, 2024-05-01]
open-dynamic-clamp/odc-1.2/hardware/odc-1.2/3d_models/B3B-XH-AM.STEP
9.90 x 10.4 x 5.75 mm

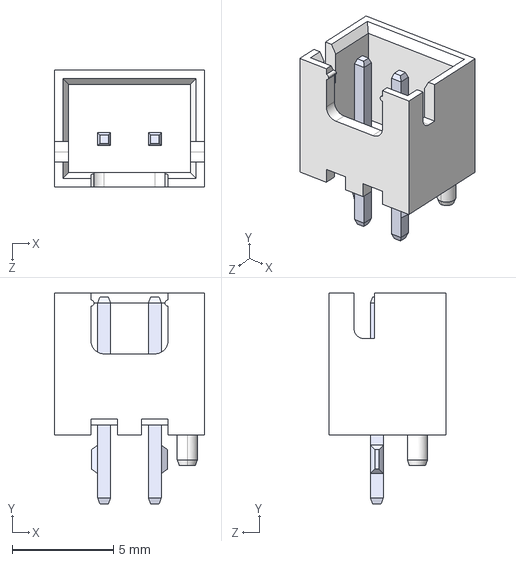
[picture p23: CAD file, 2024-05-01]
open-dynamic-clamp/odc-1.2/hardware/odc-1.2/3d_models/B2B-XH-AM.STEP
7.40 x 10.4 x 5.75 mm

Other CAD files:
open-dynamic-clamp/odc-1.2/hardware/rack-mount-enclosure/stl/faceplate-ears-left.stl

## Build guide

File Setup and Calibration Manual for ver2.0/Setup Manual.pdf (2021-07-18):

# Dynamic Clamp 2.0: Calibration and Setup

Aditya Asopa, Bhalla Lab, NCBS

Oct 2020

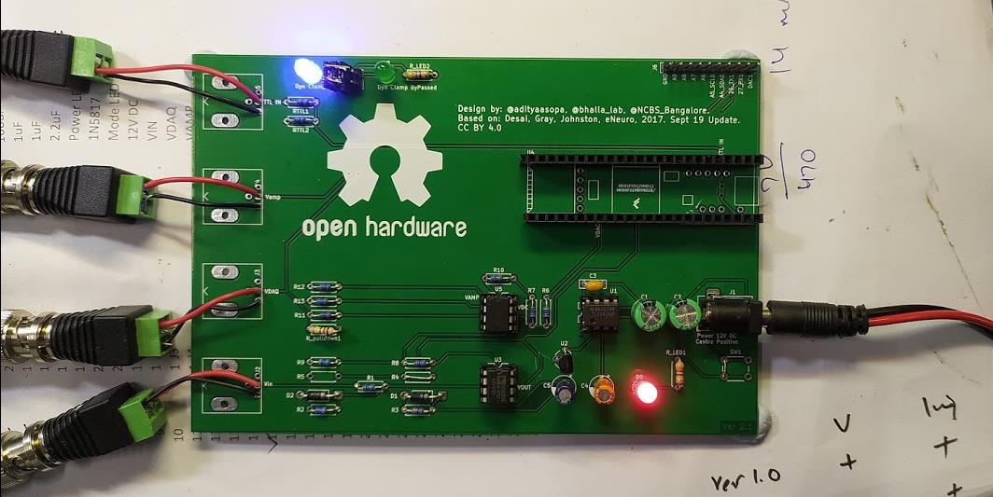
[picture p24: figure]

General Points: | 3
Circuit Schematic | 4
Stages | 6
Testing on Bench | 7
Stage 1: Voltage rails. | 7
Stage 2: 3.3V Voltage rail | 7
Stage 3: Vin -> Vout scaling by AD8031 | 7
Stage 5a: Testing the scaling of VDAC to VDC | 8
Stage 5b: Adding VDC to VDAQ | 8
Testing the Stagewise IO Relationship/Scaling Using an Oscilloscope | 10
Stage 3: AD8031 Vin --> Vout | 10
Stage 5a: LM358a, VDAC+VDAQ --> VAMP, with VDAQ = 0 | 12
Stage 5b: VDAQ + VDAC --> VAMP, with VDAC = 0 | 14
Theoretical Calibration | 16
Input Stage Calibration | 16
Output Stage Calibration | 18
Direct Calibration with a Function Generator and an Oscilloscope | 20
Calibration with a Model Cell Using Processing | 23
Input Stage calibration with Processing Program | 24
Output stage calibration with Processing Program | 25
Solution: Output stage calibration with a Script | 26
Alternative Calibration with a Teensy Program | 29
Conclusion | 31
Feeding the calibration values in Dynamic Clamp | 32
Appendix | 34
Script for alternative calibration using a Teensy program | 34
Bonus method to solve the output calibration problem with the processing calibration program | 36

### General Points:

### Testing the board

- Do not keep loose metal items on the bench around the board. They can short contacts.
- Keep the board fixed at one place, with blue tack or foam.
- Keep the benchtop tidy.
- Do not touch ICs with bare hands without grounding.
- Be careful around the capacitors even after the power supply is disconnected.
- Always disconnect power supply to the board before changing anything.
- Do not put Teensy before testing all the other stages.

### Equipment Needed

- Oscilloscope
- Function Generator (extra good if saw tooth function present, we are going to make good use of it)
- Computer with Processing, Teensy and Arduino IDE installed.
- Breadboard Jumpers
- Alligator ended BNCs
- Bench top power supply (±10V range)

### Circuit Schematic

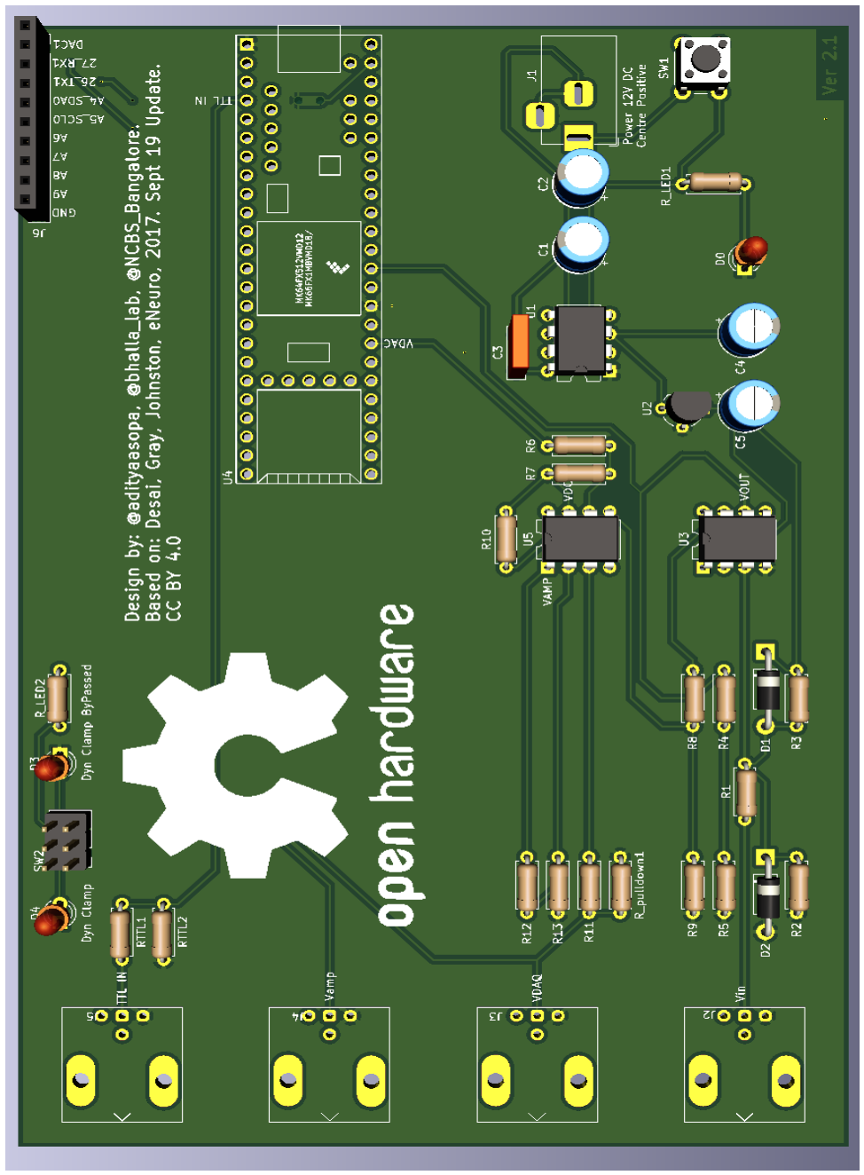
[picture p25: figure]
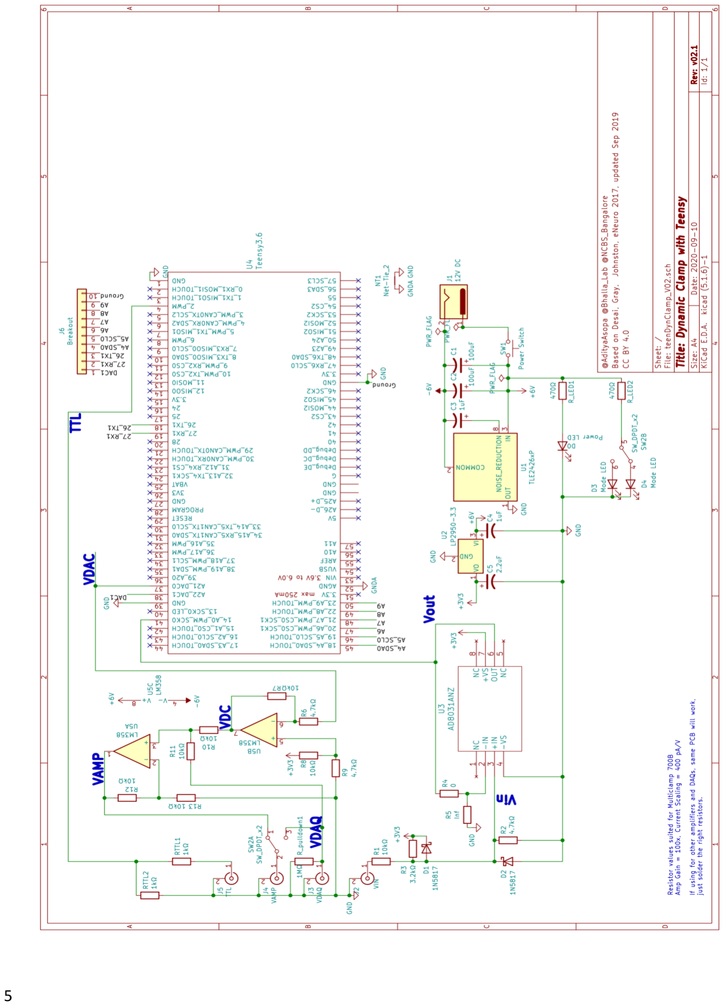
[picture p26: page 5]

### Stages

Stage | Chip | Function | Input Signal(s) | Output Signals
1 | TLE2426 | Rail Splitter, create a rail exactly the centre of supply voltage range | +/- Vsupply (9 to 24V) | (+V/2) to Gnd to (-V/2)
2 | LP2950-33 | 3.3V regulator | +V/2 to Gnd | 3.3V to Gnd
3 | AD8031 | Amplifier: scales patch amplifier readout of membrane voltage into teensy acceptable range | Vin Vin is cell voltage Vm amplified by the patch amplifier. (For axon, gain = 100x) Vm range = ±100 mV after 100x gain: Vin range = ±10 V | Vout
| Vin | Vout
Max | +10V | 3.3V
zero | 0 V | 1.65 V
Min | -10V | 0 V
4 | Teensy 3.6 | Computing conductances, producing scaled outputs for current injection | Vout | VDAC
5 | LM358 | Amplifier: produces voltage proportional to the current to be injected in the cell 5a. scales VDAC to VDC 5b. Add VDAQ to VDC | VDAC signal range: 3.3 - 0 V VDC and VDAQ | VDC range: -3V to +3V VAMP = VDC + VDAQ

The dynamic clamp circuit does not read the membrane potential of the cell directly but reads an amplified copy of it that is generated by the patch clamp amplifier. This amplification gain is kept at 100mV/V. Once calibrated, this gain should not be changed when the dynamic clamp circuit is in operation. For that reason, it is recommended that this signal be taken from secondary output of Multiclamp amplifier. This will allow us to record the membrane potential of the cell at any gain using primary output independent of the dynamic clamp.

VAMP is a voltage that is sent to the patch clamp amplifier that then injects a proportional amount of current into the patched cell. This proportionality constant can be changed in multiclamp. Usually it is set to 400pA/V. This means that if VAMP is 1 V, the patch clamp amplifier will inject 400 pA into the cell.

### Testing on Bench

Stage 1: Voltage rails.
- Bench top power supply was used.
- Connect the power supply.
- Measure voltage across the power supply jack: 18 V
- Across pin 1 of rail splitter (TLE2426) and both terminals of power supply jack: +9 V and - 9 V
- Measure voltage at pin 4 w.r.t GND: -9 V
- Measure voltage at pin 8 w.r.t GND: +9 V

Stage 2: 3.3V Voltage rail
- Measure the voltage at pin 1 of LP2950 with respect to GND: 3.30 V
- Measure the voltage at pin 7 of AD8031 with respect to GND: 3.30 V
- Measure the voltage at D1: 3.30 V

Stage 3: Vin -> Vout scaling by AD8031
- Give a linear ramp of voltage from -1 V to +1 V using a function generator at Vin BNC.
- Measure Vout with oscilloscope using a jumper probe put into pin 12 of Teensy socket (without Teensy present) or a probe touched to pin 6 of AD8031.

Fig. Vin shown in yellow (-10 to +10V) and Vout (0 to 3.3 V) shown in green, perfectly linear scaling as expected

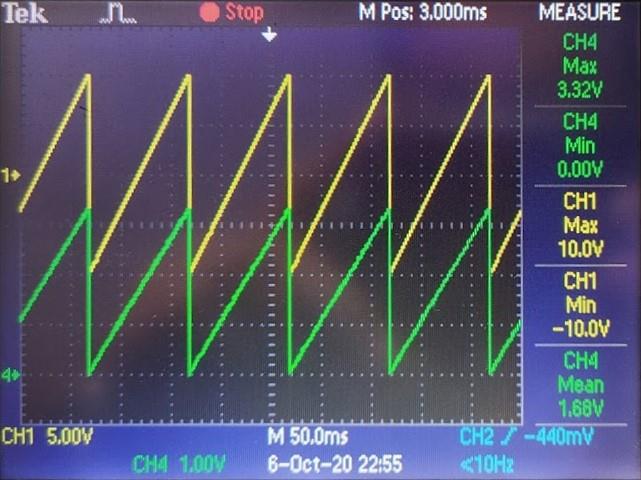
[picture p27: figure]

Stage 5a: Testing the scaling of VDAC to VDC
- Put the function generator input into VDAC pin of teensy socket w.r.t. GND.
- Input function should be a ramp from 0 to 3.3V, in the range the Teensy would generate.
- Measure output of first opAmp of LM358 pin 7 w.r.t ground.

Fig. VDAC in yellow (0.08 to 3.36 V) and VDC (6.6 to 7.4 V) in green showing linear scaling.

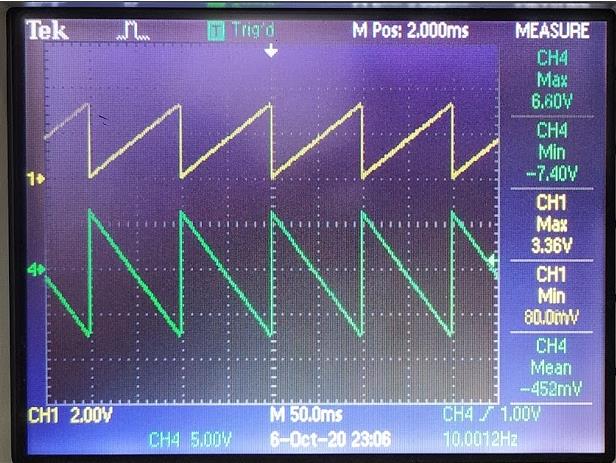
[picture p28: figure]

Stage 5b: Adding VDC to VDAQ
- VDAQ is the voltage that comes from the DAQ as the scaled version of command current that is going to injected into the cell by the amplifier. We want to add our VDC (dynamic clamp scaled voltage) to it.
- Give an analogue signal at VDAQ (BNC terminal on board) while giving another signal at VDAC (Pin 8 of teensy socket).
- Measure the resultant signal VAMP at VAMP BNC terminal or at the mode jumper terminal.

Fig. VAMP = VDC + VDAQ. Linear and inverted scaling of VDAC (0 to 3.3 V, yellow) to VDC (-3.7 to 3.3 V, pink), with VAMP (-3.6 to 3.3 V, green), when VDAQ = 0.

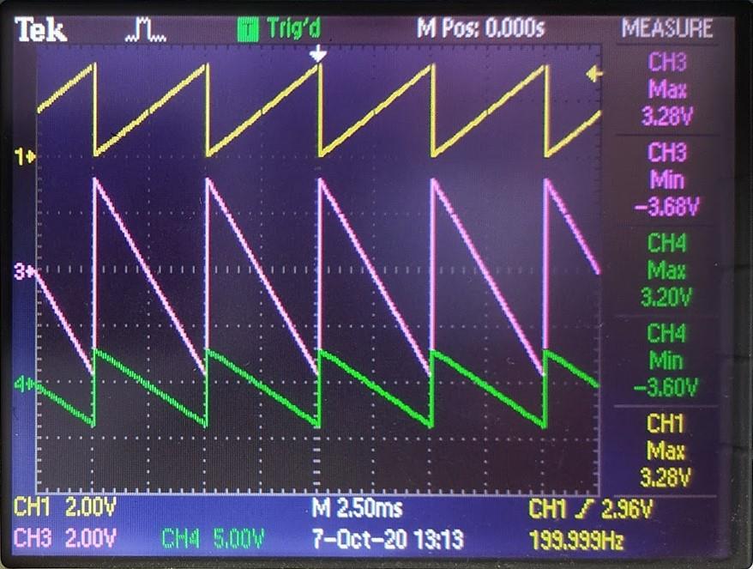
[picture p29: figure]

- Now turn VDAC to be zero and supply a voltage signal at VDAQ. Read output at VDC and VAMP.
- As VDAC is zero, VDC should be zero too, and VAMP should just be a scaled version of VDAQ signal.

Fig. VDAC is zero (yellow) and a signal is supplied at VDAQ (blue, 0 to 3 V). As a result VDC is zero and VAMP is a linearlly scaled signal proportional to VDAQ.

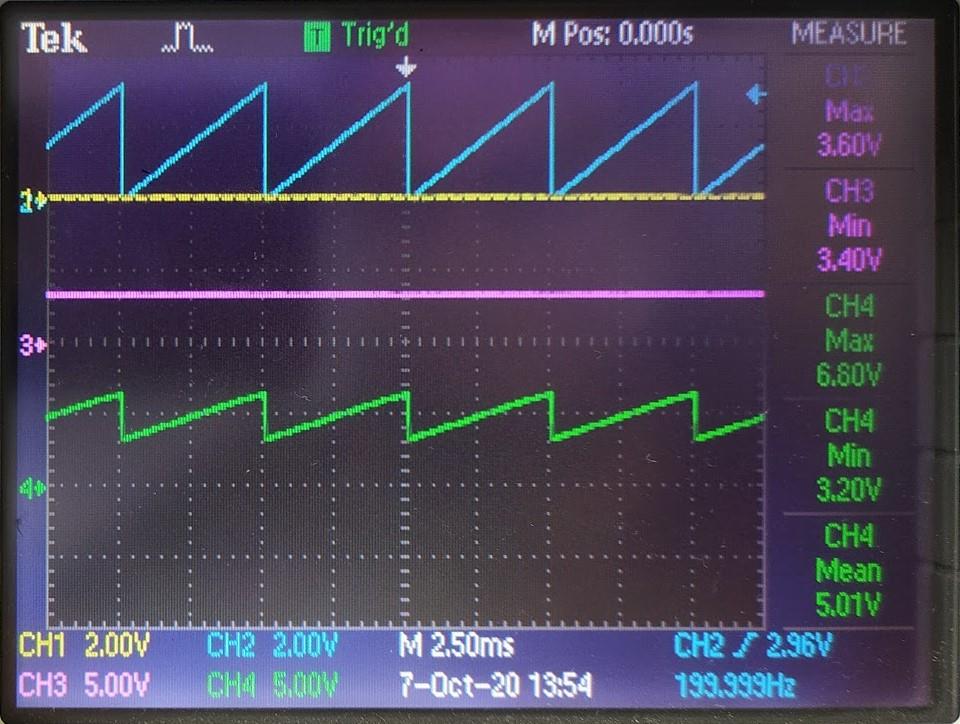
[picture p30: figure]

These quick tests show that the relationship between different signals, their ranges, scaling, and inversions are as expected.

### Testing the Stagewise IO Relationship/Scaling Using an Oscilloscope

These tests are done to test the individual modules or stages of the dynamic clamp circuit on the board. Please refer to the circuit schematic for labels and naming conventions.

Stage 3: AD8031 Vin --> Vout
Theoretical relation:

VOUT =

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
or | VOUT =

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
) ∗ VIN +
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
Given: R1 = 10kΩ, R2 = 4.7kΩ, R3 = 3.2kΩ

VOUT = 0.15993 ∗ VIN + 1.6493 | (2)

Here:

min =

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
) = 0.15993 | (2a)

And

cin =

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
) = 1.6493 | (2b)

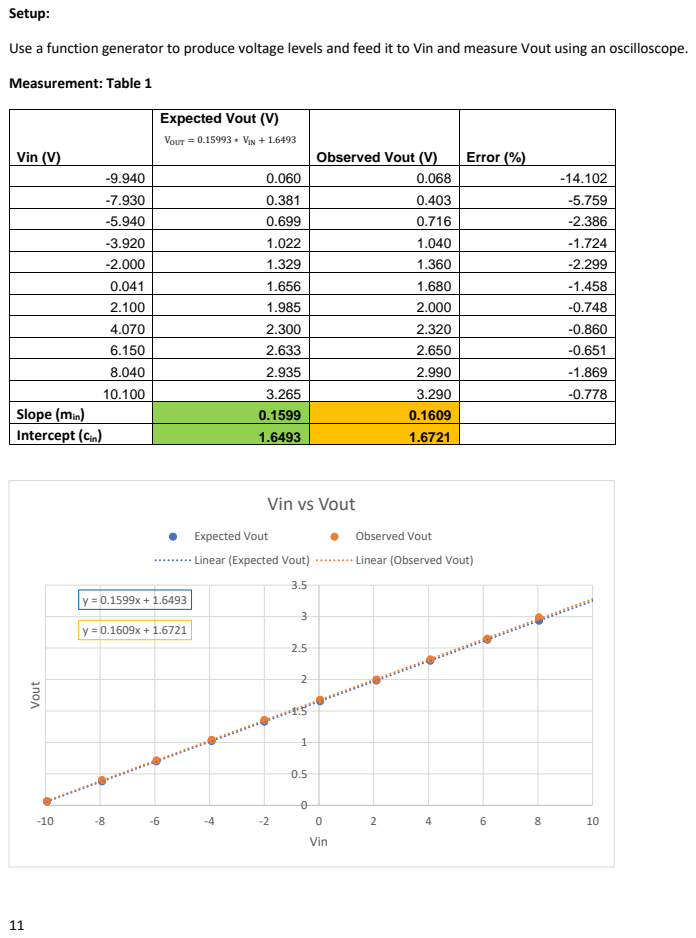
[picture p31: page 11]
Setup:; Measurement: Table 1; 10 Vout; Vin; Expected Vout; Observed Vout; Linear (Expected Vout); Linear (Observed Vout)

Use a function generator to produce voltage levels and feed it to Vin and measure Vout using an oscilloscope.

Vin (V) | Expected Vout (V) VOUT = 0.15993 ∗ VIN + 1.6493 | Observed Vout (V) | Error (%)

-9.940 | 0.060 | 0.068 | -14.102
-7.930 | 0.381 | 0.403 | -5.759
-5.940 | 0.699 | 0.716 | -2.386
-3.920 | 1.022 | 1.040 | -1.724
-2.000 | 1.329 | 1.360 | -2.299
0.041 | 1.656 | 1.680 | -1.458
2.100 | 1.985 | 2.000 | -0.748
4.070 | 2.300 | 2.320 | -0.860
6.150 | 2.633 | 2.650 | -0.651
8.040 | 2.935 | 2.990 | -1.869
10.100 | 3.265 | 3.290 | -0.778

Slope (min) | 0.1599 | 0.1609
Intercept (cin) | 1.6493 | 1.6721

Vin vs Vout

Stage 5a: LM358a, VDAC+VDAQ --> VAMP, with VDAQ = 0 Theoretical relation:

VDC = −VDAC ∗

R7
R6

+ 3.3 ∗ (

R9
R8 + R9

) (

R6 + R7
R6
) | (4)

Given: R6 = 4.7kΩ, R7 = 10kΩ, R8 = 10kΩ, R9 = 4.7kΩ

VDC = −2.1277 ∗ VDAC + 3.3

Here:

mout =

R7
R6
= −2.1277 | (4a)

And

cout = 3.3 ∗ (

R9
R8 + R9

) (

R6 + R7
R6
) = 3.3 | (4b)

And

VAMP = VDAQ + VDC

VAMP = VDAQ − 2.1277 ∗ VDAC + 3.3 | (5)

If VDAQ is GND i.e., 0 V

VAMP = VDC = −2.1277 ∗ VDAC + 3.3

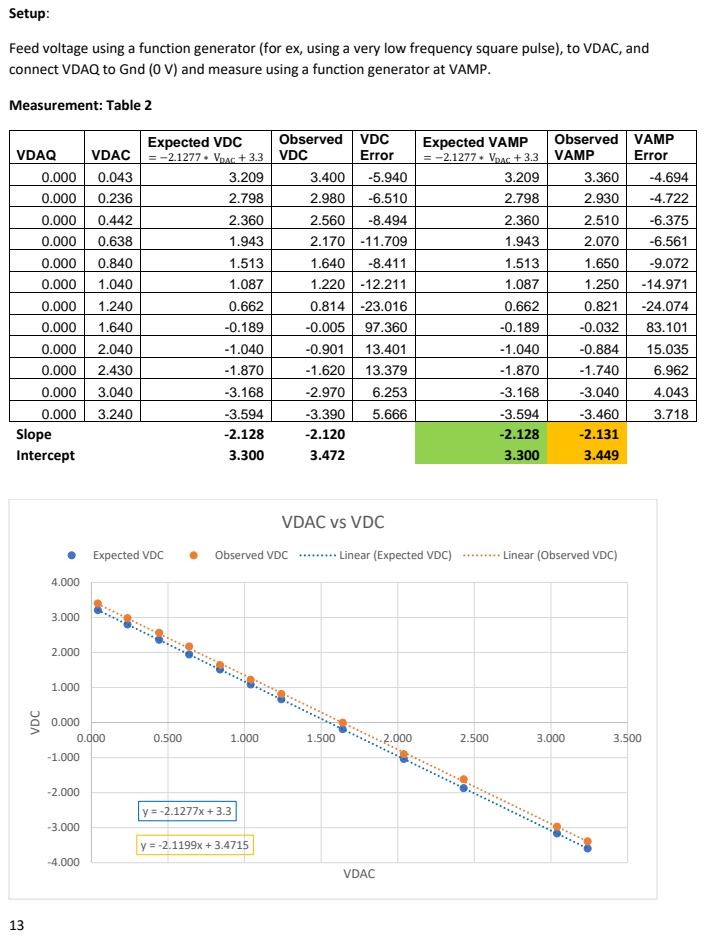
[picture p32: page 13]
Setup:; Measurement: Table 2; Slope; Intercept; VDC; VDAC; Expected VDC; Observed VDC; Linear (Expected VDC); Linear (Observed VDC)

Feed voltage using a function generator (for ex, using a very low frequency square pulse), to VDAC, and
connect VDAQ to Gnd (0 V) and measure using a function generator at VAMP.

VDAQ | VDAC | Expected VDC = −2.1277 ∗ VDAC + 3.3 | Observed VDC | VDC Error | Expected VAMP = −2.1277 ∗ VDAC + 3.3 | Observed VAMP | VAMP Error

0.000 | 0.043 | 3.209 | 3.400 | -5.940 | 3.209 | 3.360 | -4.694
0.000 | 0.236 | 2.798 | 2.980 | -6.510 | 2.798 | 2.930 | -4.722
0.000 | 0.442 | 2.360 | 2.560 | -8.494 | 2.360 | 2.510 | -6.375
0.000 | 0.638 | 1.943 | 2.170 | -11.709 | 1.943 | 2.070 | -6.561
0.000 | 0.840 | 1.513 | 1.640 | -8.411 | 1.513 | 1.650 | -9.072
0.000 | 1.040 | 1.087 | 1.220 | -12.211 | 1.087 | 1.250 | -14.971
0.000 | 1.240 | 0.662 | 0.814 | -23.016 | 0.662 | 0.821 | -24.074
0.000 | 1.640 | -0.189 | -0.005 | 97.360 | -0.189 | -0.032 | 83.101
0.000 | 2.040 | -1.040 | -0.901 | 13.401 | -1.040 | -0.884 | 15.035
0.000 | 2.430 | -1.870 | -1.620 | 13.379 | -1.870 | -1.740 | 6.962
0.000 | 3.040 | -3.168 | -2.970 | 6.253 | -3.168 | -3.040 | 4.043
0.000 | 3.240 | -3.594 | -3.390 | 5.666 | -3.594 | -3.460 | 3.718

VDAC vs VDC

### VDAC vs VAMP

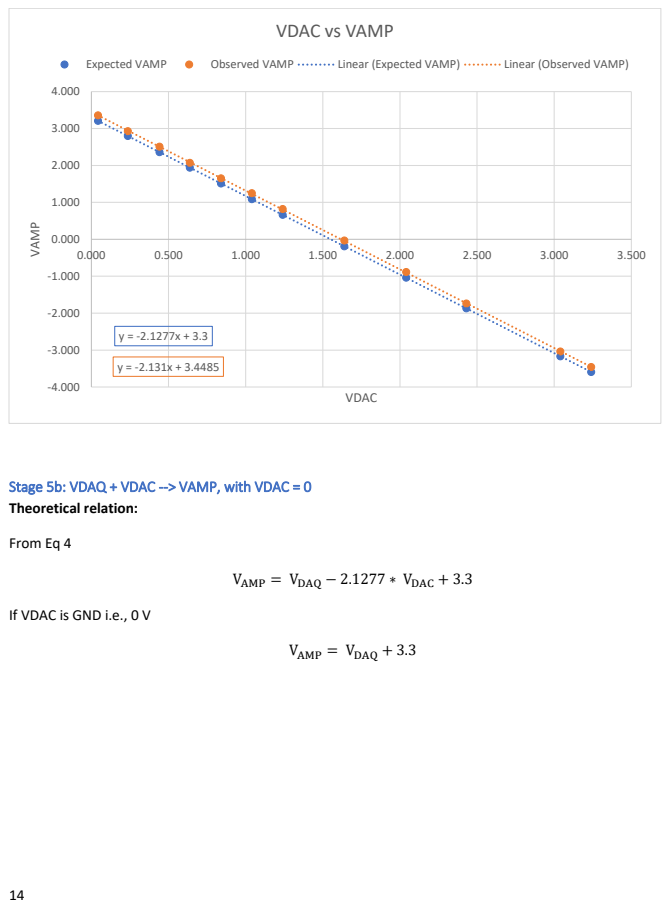
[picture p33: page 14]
From Eq 4; VAMP = VDAQ + 3.3; VAMP; VDAC; Expected VAMP; Observed VAMP; Linear (Expected VAMP); Linear (Observed VAMP)

Stage 5b: VDAQ + VDAC --> VAMP, with VDAC = 0
Theoretical relation:

VAMP = VDAQ − 2.1277 ∗ VDAC + 3.3

If VDAC is GND i.e., 0 V

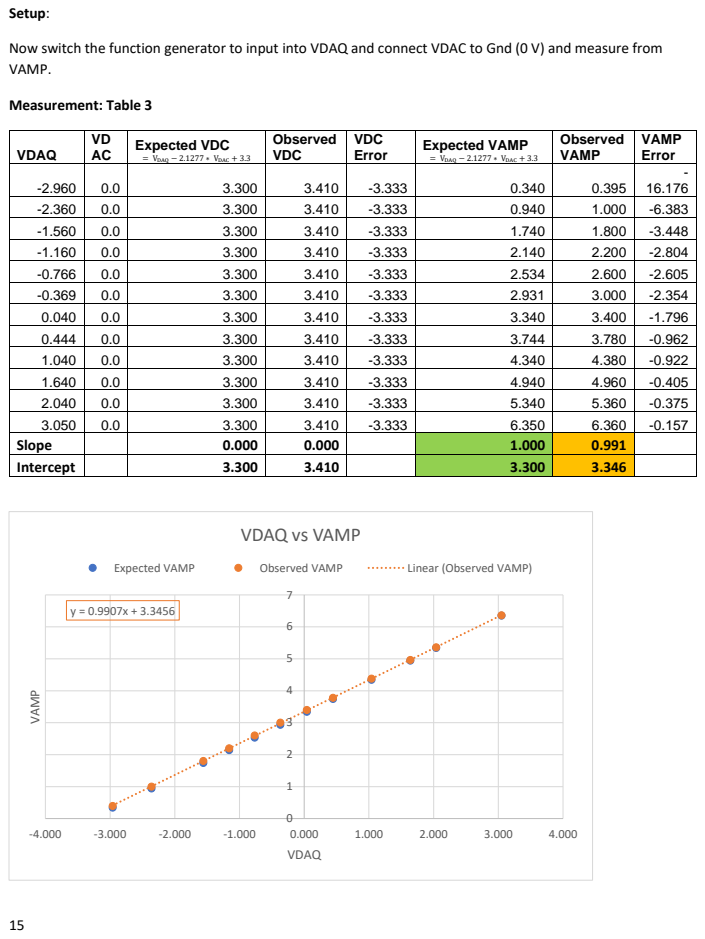
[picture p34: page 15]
Setup:; Measurement: Table 3; 4.000 VAMP; VDAQ; Expected VAMP; Observed VAMP; Linear (Observed VAMP)

Now switch the function generator to input into VDAQ and connect VDAC to Gnd (0 V) and measure from
VAMP.

VDAQ | VD AC | Expected VDC = VDAQ − 2.1277 ∗ VDAC + 3.3 | Observed VDC | VDC Error | Expected VAMP = VDAQ − 2.1277 ∗ VDAC + 3.3 | Observed VAMP | VAMP Error

-2.360 | 0.0 | 3.300 | 3.410 | -3.333 | 0.940 | 1.000 | -6.383
-1.560 | 0.0 | 3.300 | 3.410 | -3.333 | 1.740 | 1.800 | -3.448
-1.160 | 0.0 | 3.300 | 3.410 | -3.333 | 2.140 | 2.200 | -2.804
-0.766 | 0.0 | 3.300 | 3.410 | -3.333 | 2.534 | 2.600 | -2.605
-0.369 | 0.0 | 3.300 | 3.410 | -3.333 | 2.931 | 3.000 | -2.354
0.040 | 0.0 | 3.300 | 3.410 | -3.333 | 3.340 | 3.400 | -1.796
0.444 | 0.0 | 3.300 | 3.410 | -3.333 | 3.744 | 3.780 | -0.962
1.040 | 0.0 | 3.300 | 3.410 | -3.333 | 4.340 | 4.380 | -0.922
1.640 | 0.0 | 3.300 | 3.410 | -3.333 | 4.940 | 4.960 | -0.405
2.040 | 0.0 | 3.300 | 3.410 | -3.333 | 5.340 | 5.360 | -0.375
3.050 | 0.0 | 3.300 | 3.410 | -3.333 | 6.350 | 6.360 | -0.157
Slope | | 0.000 | 0.000 | | 1.000 | 0.991
Intercept | | 3.300 | 3.410 | | 3.300 | 3.346

VDAQ vs VAMP

### Theoretical Calibration

Calibration sets the relationship between amplifier and Teensy.

Input stage: relation between cell membrane voltage (Vm in mV) and the ADC values read by Teensy.

Output stage: relation between DAC values sent by Teensy and current injected by the amplifier into the cell.

Input Stage Calibration

Vin i.e., Vm after amplification by multiclamp: Vin = Vm ∗ gin

Vout produced by AD8031, from Eq. 2:

Vout = min ∗ Vin + cin

Vout digitized by Teensy into ADC:

ADC =

4096
3.3

∗ Vout

Solving for Vm and ADC:

ADC = (

4096 ∗ min ∗ gin
3.3

) ∗ Vm − (

4096
3.3
) ∗ cin | (5)

Here:

Slope Vm to ADC = (

4096 ∗ min ∗ gin
3.3

)

And

Intercept Vm to ADC = (

4096
3.3

) ∗ cin

Teensy should know the ADC to Vm conversion. In the dynamic clamp program that goes on the teensy for operation, we need to feed the input slope and input intercept. When we put together the whole board and do calibration, we will change the Vm and record the ADC values from Teensy. From that we will get the "Intercept Vm to ADC" and "Slope Vm to ADC" values. Using that we must obtain the inverse relationship i.e., slope and intercept to get Vm values from ADC values.

Vm = (

3.3
4096 ∗ min ∗ gin

) ∗ ADC − (

cin

min ∗ gin

) | (6)

Here:

Input Slope = (

3.3
4096 ∗ min ∗ gin
) | (6a)

Input Intercept = (−

cin

min ∗ gin

) | (6b)

Calculation: Table 4

Quantity | Value | Unit
Vm | -65.00 | mV

Gain of Amp
stage 1 | 10 | x
Stage 2 | 10 | x
Total Input Gain | 100 | mV/mV
Digitization Max Voltage | 3.3 | V
Digitization Bit depth | 4096 | levels
IO relation (from Table 1) | Expected | According to Observed Scaling
Slope Vout to Vin (m_in) | 0.1599 | 0.1609
Intercept Vout to Vin (c_in) | 1.6493 | 1.6721

Vm to ADC
Slope Vm to ADC | 19.84698182 | 19.9711
Intercept Vm to ADC | 2047.131152 | 2075.431

Inverse relationship
Input Slope | 0.050385495 | 0.050072
Input Intercept | -103.1457161 | -103.922

Output Stage Calibration

VAMP = VDC

VDC = mout ∗ VDAC + cout

VDAC = (

3.3
4096) ∗ DAC

Iinj = gout ∗ VAMP

Combining all:

Iinj = (

3.3 ∗ mout ∗ gout
4096 | ) ∗ DAC + (cout ∗ gout) | (7)

And inversely:

DAC = (

4096 3.3 ∗ mout ∗ gout | ) ∗ Iinj + (− 4096 ∗ cout
| 3.3 ∗ mout
) | (8)

Here:

Output Slope =

4096
3.3 ∗ mout ∗ gout

(8a)

Output Intercept = −

4096 ∗ cout
3.3 ∗ mout

(8b)

During calibration, using processing calibration program with a model cell, the teensy wants to figure out the output relationship i.e., how much DAC value gets converted to how much current injection into the cell. For that, teensy generates an array of DAC values, and then measures the Vm of the model cell (in form of the ADC values). From Vm and resistance of the model cell, it calculates how much current is sent to the model cell.

We must empirically find Input and Output slopes and intercepts.

Table 5

Quantity | Value | Unit
Iinj | -100.00 | pA
Total Output Gain | 400 | pA/V
Digitization Max Voltage | 3.3 | V
Digitization Bit depth | 4096 | Levels
IO relation from Table 2 | Expected | According to Observed Scaling
Slope (mout) | -2.1277 | -2.131
Intercept (cout) | 3.3 | 3.4485

DAC to Iinj
Slope | -0.68568457 | -0.68675
Intercept | 1320 | 1379.4

Inverse relationship
Output Slope | -1.458396533 | -1.45614
Output Intercept | 1925.083423 | 2008.597

### Direct Calibration with a Function Generator and an Oscilloscope

In direct calibration, we can give a certain known value on the input side of the stage and measure the value on the output side. From the measurements, if we fit a line, we can get the slope and intercept of that relationship. This can be done using a function generator and an oscilloscope without the need of a model cell.

### Input Stage Calibration: Vin → ADC

Setup:

Put Teensy into circuit. Using a function generator, give known constant voltages to Vin and read ADC values recorded by Teensy. Measure the ADC to Vin relationship.

Measurement: Table 6, Compare with theoretical values from table 4

Input Vin Using a function Gen (V) | Equivalent Vm (mV) | Measured ADC Value
-9 | -90 | 200
-8 | -80 | 402
-7 | -70 | 603
-6 | -60 | 803
-5 | -50 | 1004
-4 | -40 | 1204
-3 | -30 | 1405
-2 | -20 | 1606
-1 | -10 | 1805
0 | 0 | 2005
1 | 10 | 2206
2 | 20 | 2406
3 | 30 | 2610
4 | 40 | 2810
5 | 50 | 3012
6 | 60 | 3215
7 | 70 | 3419
8 | 80 | 3620
9 | 90 | 3820
Input Slope | 0.0497
Input Intercept | -99.892

### Equivalent Vm (mV)

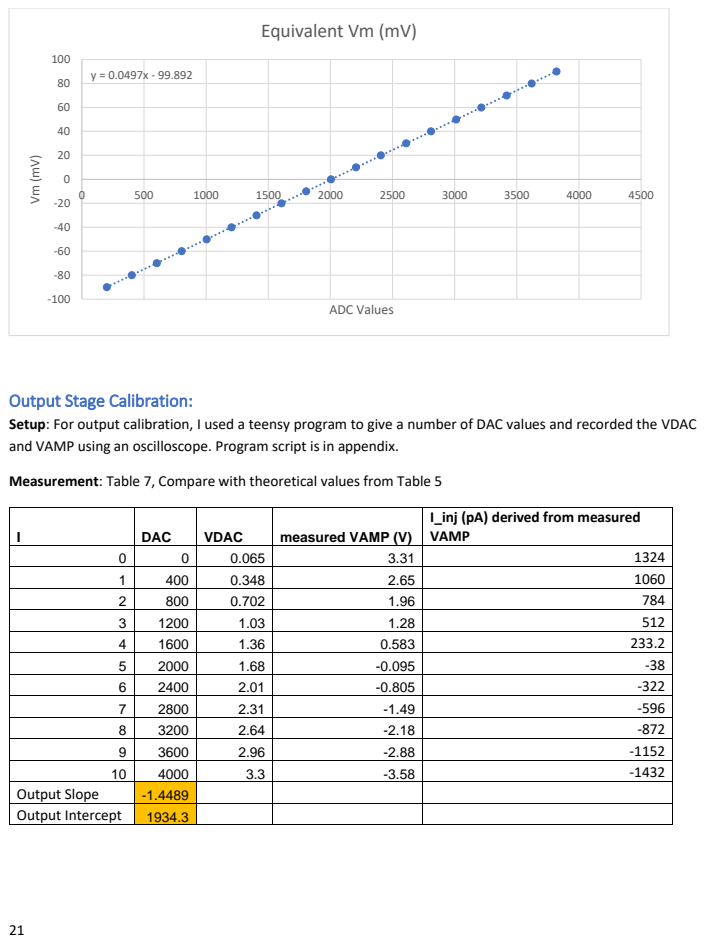
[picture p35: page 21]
ADC Values

Output Stage Calibration:
Setup: For output calibration, I used a teensy program to give a number of DAC values and recorded the VDAC
and VAMP using an oscilloscope. Program script is in appendix.

Measurement: Table 7, Compare with theoretical values from Table 5

I | DAC | VDAC | measured VAMP (V) | I_inj (pA) derived from measured VAMP

0 | 0 | 0.065 | 3.31 | 1324
1 | 400 | 0.348 | 2.65 | 1060
2 | 800 | 0.702 | 1.96 | 784
3 | 1200 | 1.03 | 1.28 | 512
4 | 1600 | 1.36 | 0.583 | 233.2
5 | 2000 | 1.68 | -0.095 | -38
6 | 2400 | 2.01 | -0.805 | -322
7 | 2800 | 2.31 | -1.49 | -596
8 | 3200 | 2.64 | -2.18 | -872
9 | 3600 | 2.96 | -2.88 | -1152
10 | 4000 | 3.3 | -3.58 | -1432

Output Slope | -1.4489
Output Intercept | 1934.3

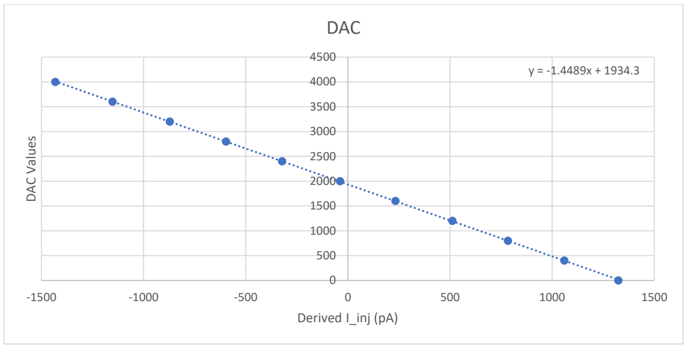
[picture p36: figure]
1500 DAC Values; Derived I_inj (pA); DAC

### Calibration with a Model Cell Using Processing

Now dynamic clamp can be boxed and put into connection with the Axon devices. Remember the dynamic clamp stage 1 is designed to read a 100x amplified Vm between the range ±10V. Multiclamp, the patch clamp amplifier sends a secondary output that can be selected to be a scaled copy of membrane potential Vm. It should have the same gain settings of 10, which gives an amplification of 100 mV/mV (i.e., 100x)¹
. We will use
this output from multiclamp to read cell Vm.,

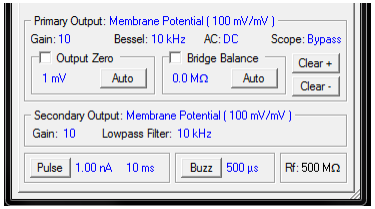
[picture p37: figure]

Setup:

Instructions are described in the original documentation. Plug in a model cell, switch to current clamp on multiclamp and remove any offsets so that model cell Vm is 0 mV at 0 pA current injection.

Calibration will be done using the graphical interface written in processing and can be found in the Dynamic Clamp directory. First, we have to upload the teensy_calibration.ino file to Teensy and then use Processing program processing_calibration.pde to measure input and output slopes and intercepts that we have been doing manually so far.

If you go through the theoretical calibration steps and formulae as described in earlier sections, it will be clear that the calibration values, intercepts, and slopes are entirely a function of resistors and amplifiers used in the circuit and ADC – DAC range of the Teensy and do not depend on the multiclamp amplifier and DAQ.

1 Multiclamp has an internal gain of 10x that cannot be changed. So, when we select a gain of 10 in the user interface, the actual gain is 10 *10 = 100. Refer to table 4.

Input Stage calibration with Processing Program Table 8

Input Gain | 100
Vm (mV) | ADC reading
0.000 | 2014
-10.800 | 1803
-31.091 | 1407
-54.000 | 960
-80.182 | 449
80.182 | 3576
63.818 | 3255
40.909 | 2807
20.618 | 2411
Input Slope | 0.0513
Input Intercept | -103.27

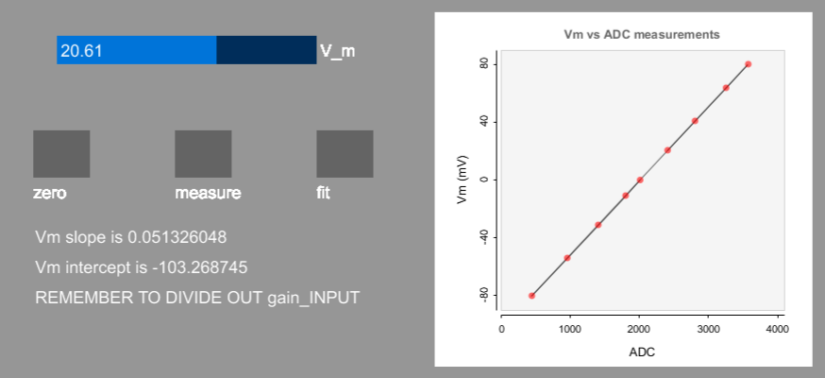
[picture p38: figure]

The output of slope and intercept have to fed into the dynamic clamp main program dynamic_clamp.ino after multiplying with the gain (100).

50 | const float inputSlope = 5.13/gain_INPUT.
51 | const float inputIntercept = -10327/gain_INPUT.

Output stage calibration with Processing Program

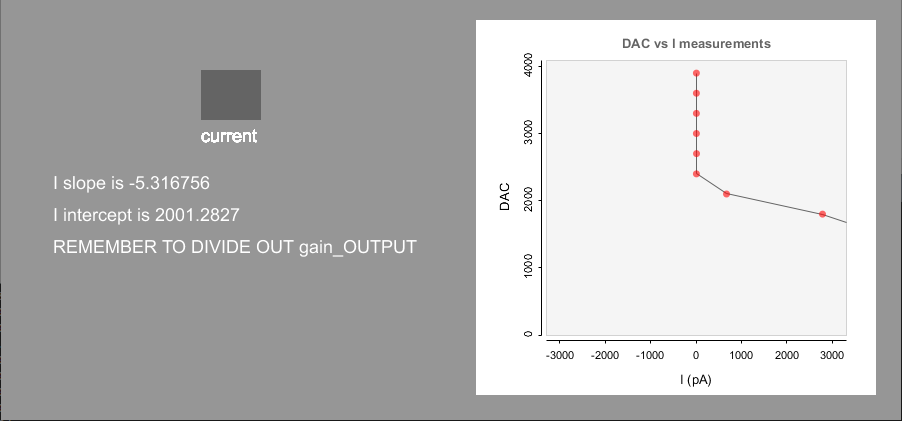
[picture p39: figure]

The processing program generates an error. The reason is that in the backend, the output calibration generates DAC values from 300 to 3900, which in turn would create a VAMP of ±1.4nA. The program then measures the Vm, derives Iinj from Vm (using user supplied model cell resistance). Normally, for a patched cell (Rm ~ 100 MΩ, this current would create a Vm of around ±100 mV. But when a model cell is used (Rm ~ 500 MΩ) the Vm goes beyond 600 mV and corresponding Vin goes to 65 V, which is far beyond the range of dynamic clamp input and thus for most of the DAC values, Vm on model cell is unmeasurable.

Table 9: Problem with output slope measurement

DAC | Expected VAMP (approx.) | Corresponding I_inj | Vm on Model cell (mV) | Vin going into DynClamp (V) | In Range of Teensy? (±10V)
0 | 3.3 | 1320 | 671.88 | 67.188 | FALSE
300 | 2.82 | 1128 | 574.152 | 57.4152 | FALSE
600 | 2.34 | 936 | 476.424 | 47.6424 | FALSE
900 | 1.86 | 744 | 378.696 | 37.8696 | FALSE
1200 | 1.38 | 552 | 280.968 | 28.0968 | FALSE
1500 | 0.9 | 360 | 183.24 | 18.324 | FALSE
1800 | 0.42 | 168 | 85.512 | 8.5512 | TRUE
2100 | -0.06 | -24 | -12.216 | -1.2216 | TRUE
2400 | -0.54 | -216 | -109.944 | -10.9944 | FALSE
2700 | -1.02 | -408 | -207.672 | -20.7672 | FALSE
3000 | -1.5 | -600 | -305.4 | -30.54 | FALSE
3300 | -1.98 | -792 | -403.128 | -40.3128 | FALSE
3600 | -2.46 | -984 | -500.856 | -50.0856 | FALSE
3900 | -2.94 | -1176 | -598.584 | -59.8584 | FALSE
4095 | -3.252 | -1300.8 | -662.107 | -66.21072 | FALSE

Resulting into the above plot or the one below

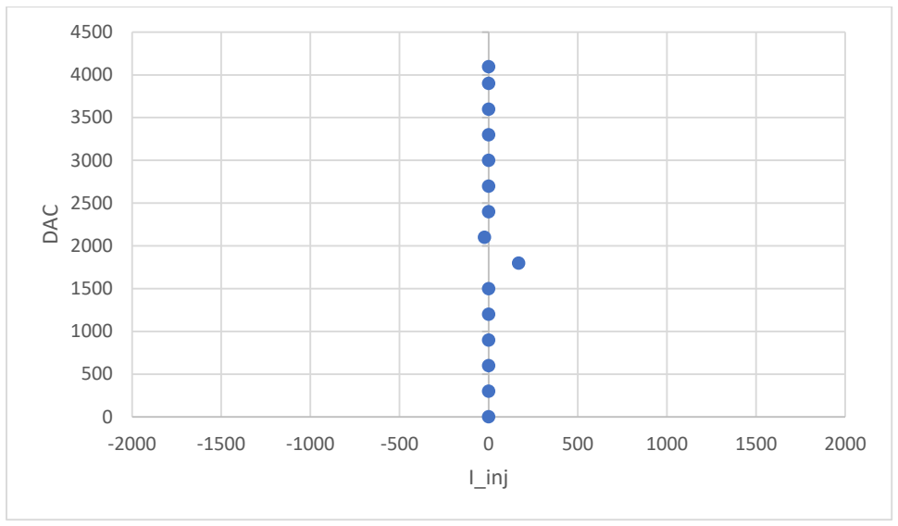
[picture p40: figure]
DAC; I_inj

Solution: Output stage calibration with a Script
There are two ways to solve this problem. Either we can use a model cell with lower resistance, or we can change the range of DAC values that are used in the processing program. There is a bonus method to solve the problem describer in the appendix.

Modifying the processing_calibration.pde program, line 29-31.

// DAC outputs between 300 and 3900 in increments of 300 29 for (int z=0; z<nOutputs; z++) {
30 outputs[z] = 300*(z+1);
31 }
Change to:

// DAC outputs between 1800 and 2300 in increments of 30 29 for (int z=0; z<nOutputs; z++) {
30 outputs[z] = 1750+30*(z+1);
31 }

Note: You may need to tweak the increment value a bit to get a range in which all values come out right. Between 1800 and 2300, we need 13 values as nOutputs is fixed at 13, therefore, the right increment would be
30. Do a check, nevertheless.

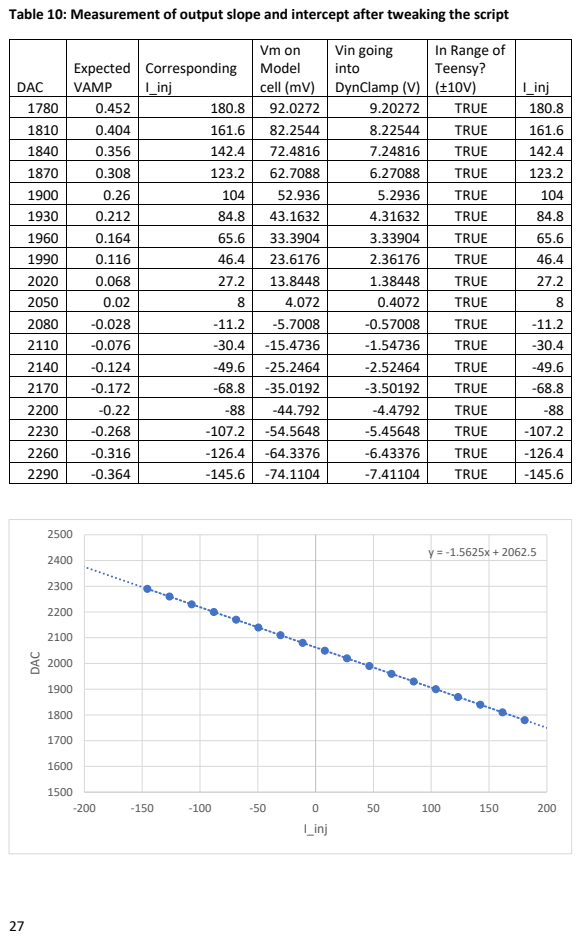
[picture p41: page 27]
DAC; I_inj

Table 10: Measurement of output slope and intercept after tweaking the script

DAC | Expected VAMP | Corresponding I_inj | Vm on Model cell (mV) | Vin going into DynClamp (V) | In Range of Teensy? (±10V) | I_inj

1780 | 0.452 | 180.8 | 92.0272 | 9.20272 | TRUE | 180.8
1810 | 0.404 | 161.6 | 82.2544 | 8.22544 | TRUE | 161.6
1840 | 0.356 | 142.4 | 72.4816 | 7.24816 | TRUE | 142.4
1870 | 0.308 | 123.2 | 62.7088 | 6.27088 | TRUE | 123.2
1900 | 0.26 | 104 | 52.936 | 5.2936 | TRUE | 104
1930 | 0.212 | 84.8 | 43.1632 | 4.31632 | TRUE | 84.8
1960 | 0.164 | 65.6 | 33.3904 | 3.33904 | TRUE | 65.6
1990 | 0.116 | 46.4 | 23.6176 | 2.36176 | TRUE | 46.4
2020 | 0.068 | 27.2 | 13.8448 | 1.38448 | TRUE | 27.2
2050 | 0.02 | 8 | 4.072 | 0.4072 | TRUE | 8
2080 | -0.028 | -11.2 | -5.7008 | -0.57008 | TRUE | -11.2
2110 | -0.076 | -30.4 | -15.4736 | -1.54736 | TRUE | -30.4
2140 | -0.124 | -49.6 | -25.2464 | -2.52464 | TRUE | -49.6
2170 | -0.172 | -68.8 | -35.0192 | -3.50192 | TRUE | -68.8
2200 | -0.22 | -88 | -44.792 | -4.4792 | TRUE | -88
2230 | -0.268 | -107.2 | -54.5648 | -5.45648 | TRUE | -107.2
2260 | -0.316 | -126.4 | -64.3376 | -6.43376 | TRUE | -126.4
2290 | -0.364 | -145.6 | -74.1104 | -7.41104 | TRUE | -145.6

Measurement after processing code change:

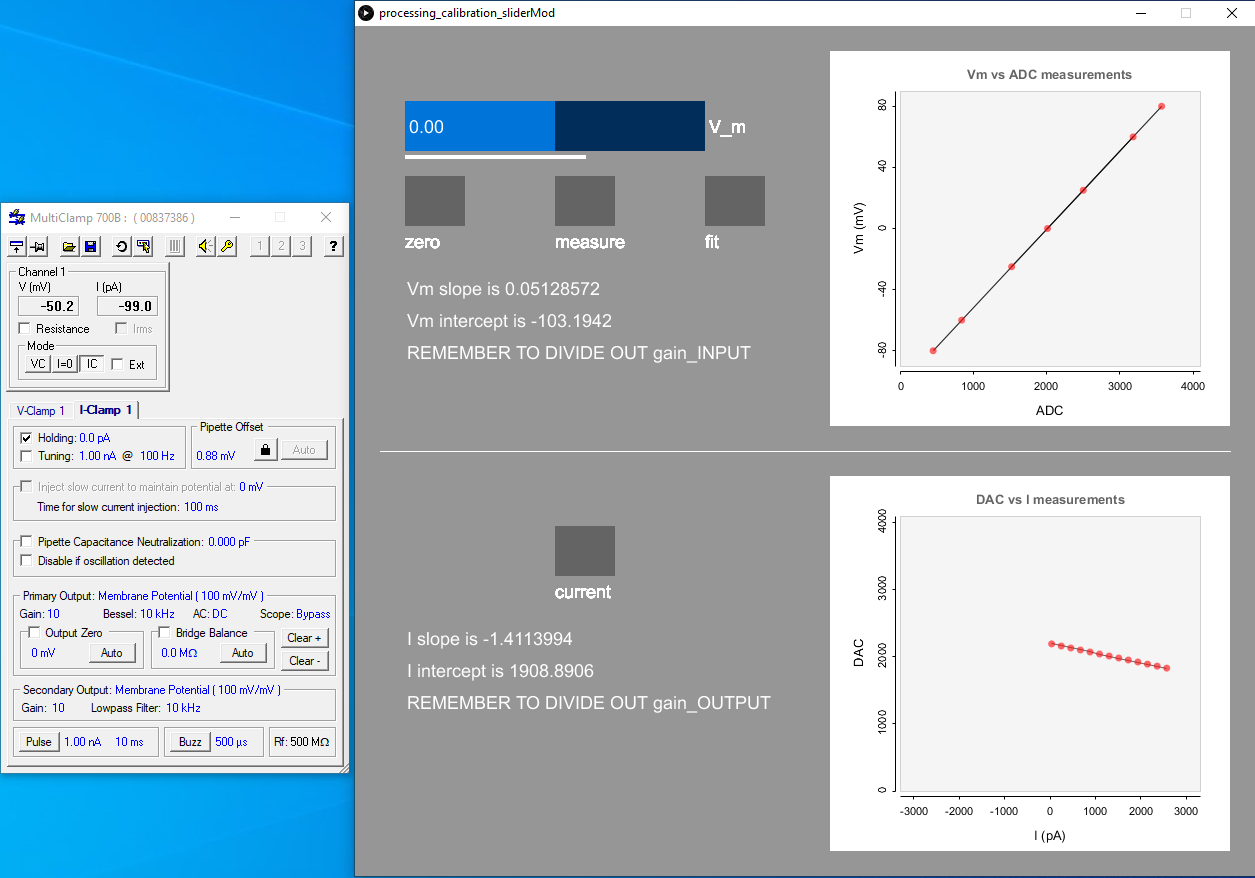
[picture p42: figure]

Note: The fitting values are different from the table as this sample plot is generated from another dynamic clamp setup for demonstration.

### Alternative Calibration with a Teensy Program

Another way to measure the input and output slopes and intercepts is to do it manually.

Setup: Script to do that can be found in the appendix.

i) Change Vm in current clamp in the multiclamp commander, measure ADC values. Plot and fit a line. Get intercept and slope of the fit. These will be input intercept and slope.
ii) | Then, use another script to change DAC values, and measure ADC values. From ADC values get Vm
| using the relationship obtained in step (i). Get I_inj by dividing Vm with model cell resistance. Plot
| DAC vs I_inj. Fit a line, get the slope, and intercept values from the fit. These will be your output
| intercept and slope.

Measurement: Input Calibration

Table 11

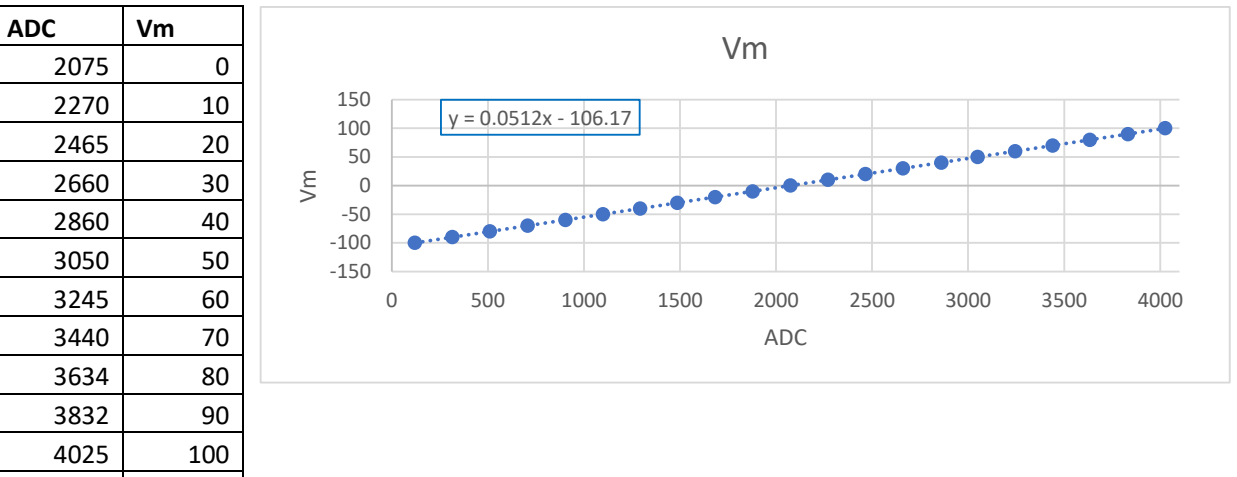
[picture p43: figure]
ADC

1878 | -10
1683 | -20
1486 | -30
1292 | -40
1098 | -50
903 | -60
706 | -70
510 | -80
315 | -90
120 | -100
input slope | 0.0512
input intercept | -106.17

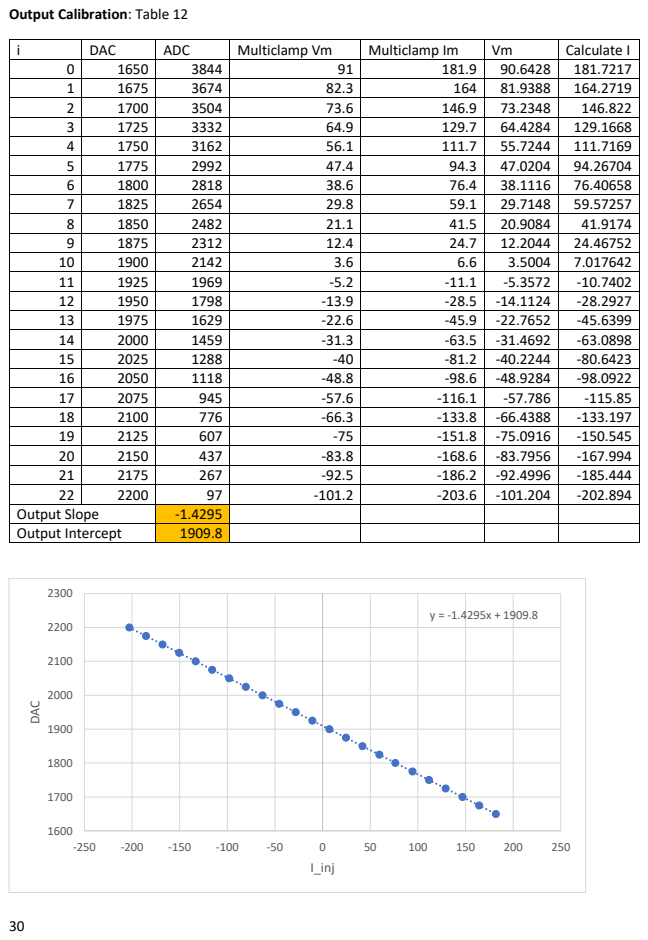
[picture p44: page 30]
DAC; I_inj

Output Calibration: Table 12

i | DAC | ADC | Multiclamp Vm | Multiclamp Im | Vm | Calculate I

0 | 1650 | 3844 | 91 | 181.9 | 90.6428 | 181.7217
1 | 1675 | 3674 | 82.3 | 164 | 81.9388 | 164.2719
2 | 1700 | 3504 | 73.6 | 146.9 | 73.2348 | 146.822
3 | 1725 | 3332 | 64.9 | 129.7 | 64.4284 | 129.1668
4 | 1750 | 3162 | 56.1 | 111.7 | 55.7244 | 111.7169
5 | 1775 | 2992 | 47.4 | 94.3 | 47.0204 | 94.26704
6 | 1800 | 2818 | 38.6 | 76.4 | 38.1116 | 76.40658
7 | 1825 | 2654 | 29.8 | 59.1 | 29.7148 | 59.57257
8 | 1850 | 2482 | 21.1 | 41.5 | 20.9084 | 41.9174
9 | 1875 | 2312 | 12.4 | 24.7 | 12.2044 | 24.46752
10 | 1900 | 2142 | 3.6 | 6.6 | 3.5004 | 7.017642
11 | 1925 | 1969 | -5.2 | -11.1 | -5.3572 | -10.7402
12 | 1950 | 1798 | -13.9 | -28.5 | -14.1124 | -28.2927
13 | 1975 | 1629 | -22.6 | -45.9 | -22.7652 | -45.6399
14 | 2000 | 1459 | -31.3 | -63.5 | -31.4692 | -63.0898
15 | 2025 | 1288 | -40 | -81.2 | -40.2244 | -80.6423
16 | 2050 | 1118 | -48.8 | -98.6 | -48.9284 | -98.0922
17 | 2075 | 945 | -57.6 | -116.1 | -57.786 | -115.85
18 | 2100 | 776 | -66.3 | -133.8 | -66.4388 | -133.197
19 | 2125 | 607 | -75 | -151.8 | -75.0916 | -150.545
20 | 2150 | 437 | -83.8 | -168.6 | -83.7956 | -167.994
21 | 2175 | 267 | -92.5 | -186.2 | -92.4996 | -185.444
22 | 2200 | 97 | -101.2 | -203.6 | -101.204 | -202.894
Output Slope | | -1.4295
Output Intercept | | 1909.8

### Conclusion

The whole objective of all the step by step and stage-by stage exercise was to finally, determine the relationship between what Dynamic Clamp measures and what Dynamical Clamp maps it to. It has to map the readout on it is pin 0, i.e., ADC to Vm and also map its output from DAC onto the injected current Iinj.

In the dynamic clamp setup that was made along with the writing of this manual, the input-output intercepts and slopes came out to be:

Table 13

Input Slope | 0.0513
Input Intercept | -103.27
Output Slope | -1.4321
Output Intercept | 1913.6

Finally, we have to put these values into the dynamic_clamp.ino file.

Summary of Values, errors in different measurements:

Either of the green shaded column values can be used.

| Theoretical | Expected From Individual Modules | Direct From Individual Modules with Function Gen | Whole Setup with Processing GUI and Model Cell | Whole Setup Direct with Code and Model Cell | % Error Between Theoretical and Direct with Code
Input Slope | 0.050 | 0.050 | 0.050 | 0.051 | 0.051 | 1.617
Input Intercept | -103.146 | -103.922 | -99.892 | -103.270 | -106.170 | 2.932
Output Slope | -1.458 | -1.456 | -1.449 | -1.432 | -1.430 | -1.981
Output Intercept | 1925.083 | 2008.597 | 1934.300 | 1913.600 | 1909.800 | -0.794

### Feeding the calibration values in Dynamic Clamp

The input and output intercepts and slopes obtained in sections above and summarized in the last section need one more modification before being put into the dynamic clamp program. Recall from Equation 6 and Table 13 for input that:

Input Slope = (

3.3
4096 ∗ min ∗ gin

) = 0.0513

And

Input Intercept = (−

cin

min ∗ gin

) = −103.27

As one can see, both quantities are dependent on amplifier input gain gin. To make the code more general to be used with different values of input gain, we can take gin out and use it as another variable.

Input Slope = (

3.3
4096 ∗ min ∗ gin

) =

5.13

gin

And

Input Intercept = (−

cin

min | ∗ gin
) = | −

10327

gin

Similary, to make the dynamic clamp code more general to be used with different values of gout, we need to factor out gout from equations 8a and 8b.

Output Slope =

4096
3.3 ∗ mout ∗ gout

(8a)

Output Intercept = −

4096 ∗ cout
3.3 ∗ mout

(8b)

From 8b, we can see the output intercept does not depend on gout. The final value from 8a and Table 13:

Output Slope =

4096
3.3 ∗ mout ∗ gout

= −

1.430 ∗ 400

gout

=

572

gout

Output Intercept = −

4096 ∗ cout
3.3 ∗ mout

Rest all constants, min, mout, cin, cout, 4096, and 3.3 are property of the circuit and are not changeable from outside.

Feed the final values in Dynamic_Clamp.ino file:

50 const float inputSlope = 5.12/gain_INPUT;
51 const float inputIntercept = -10617/gain_INPUT; 52 const float outputSlope = -571.8/gain_OUTPUT; 53 const float outputIntercept = 1909.8;

### Appendix

Script for alternative calibration using a Teensy program
//+++++++++++++++++++++++++++++++++++++++++++++++++++++++++++++++++++++++ /*
Analog input, analog output, serial output
Aditya Asopa, Bhalla lab, NCBS Oct 2020
*/

// These constants won't change. They are used to give names to the pins used:
// Analog input pin that the Vm is read from
const int analogInPin = A0;
// Analog output pin that the DAC goes out from
const int analogOutPin = A21;
int sensorValue = 0; | // value read from the ADC
int outputValue = 0; | // value output to the DAC

void setup() {
// initialize serial communications at 115200 bps: Serial.begin(115200);
analogWriteResolution(12);
//very important to set the bit resolution analogReadResolution(12);
}
/*Teensy cant read any value of Vm that is beyond +/-100mV.
* Since the model cell has a resistance of 500MΩ, a Vm of 100mV is produced with a current of 200pA.
* Therefore, IDC has to be between +/- 200pA.
* For that, corresponding DAC has to be between 1800 - 2300 (check the previous sheet for scaling).
* Therefore, the right range of DAC to give here is 1750 to 2300.
*/
void loop() {
for (int i = 0; i <= 20; i++) {
//outputSlope * injectionCurrent + outputIntercept;
int Iinj = i*30+1750;
// make sure the output is an integer between 0 and 4095 (12 bits) int DAC = constrain((int)Iinj,0,4095); analogWrite(analogOutPin,DAC);
delay(1000);
int adc = analogRead(analogInPin);

Serial.println(i);
Serial.print("\t");
Serial.print(DAC);
Serial.print("\t")
Serial.print(adc);
delay(1000);
}
}
//++++++++++++++++++++++++++++++++++++++++++++++++++++++++++++++++++++++++++++++++++++

Bonus method to solve the output calibration problem with the processing calibration program

As described in the section, the problem arises due to huge resistance of the model cell, the Vm drop after amplification goes out of the range of Teensy ADC. We can therefore also solve the problem by changing not the resistance of model cell but by changing the gain of the amplifier and then factoring it back in (recall Eq. 8)

Steps:
1. Keep the input gain at 10 (100mV/mV). Measure the input slope and intercept like usual.
2. Change the gain to 1 (10 mV/mV). Run the output stage calibration.
3. Factor back the gain into the calculation before plugging into dynamic clamp program.

Sample result:

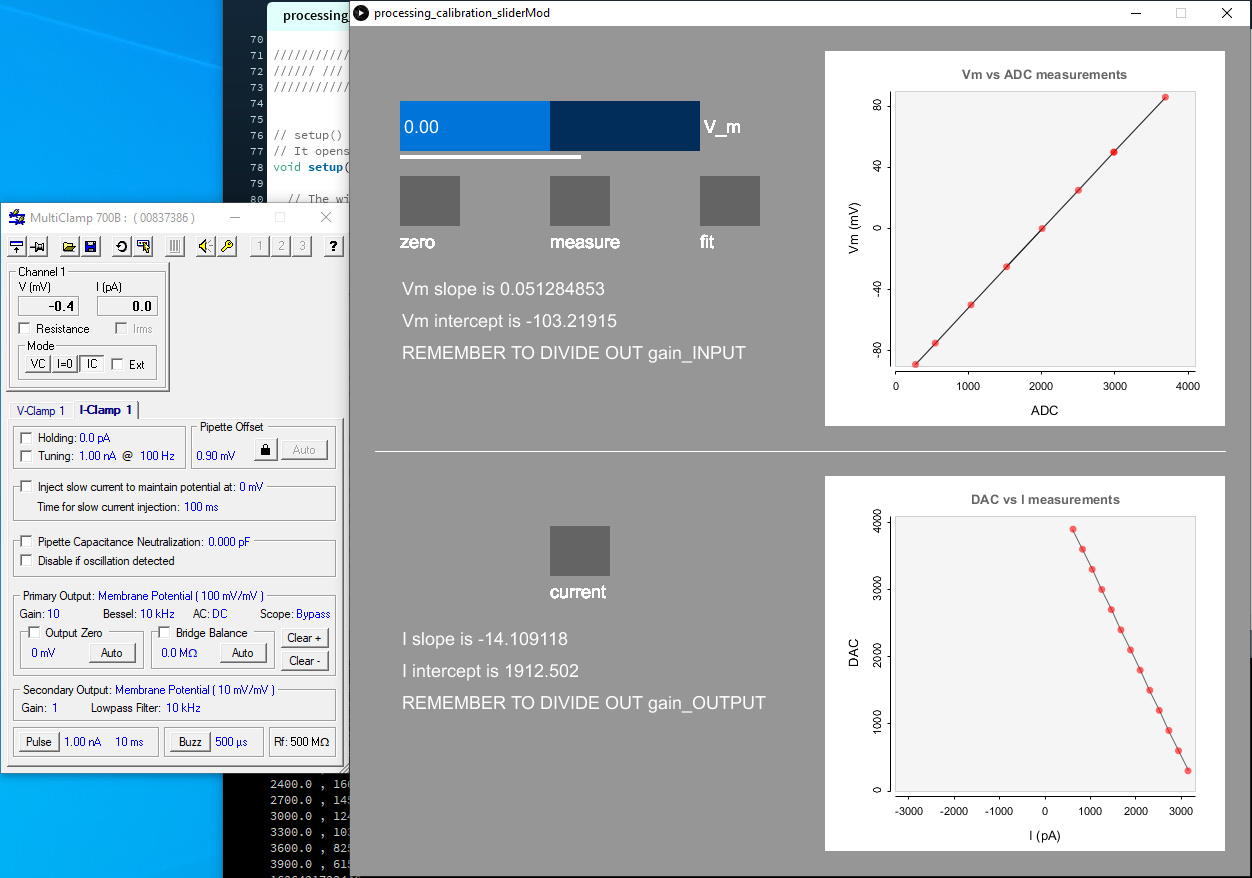
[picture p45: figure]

So, the correct output values to be put into the dynamic_clamp.ino program will be:

Output slope = -1.410911/gout and
Output intercept = 1912.502

See if you can figure out why output slope had to be divided by 10 and intercept was left as is. Hint: input gain.

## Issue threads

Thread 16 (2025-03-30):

Capability to feed pre-measured excitatory and inhibitory conductances into device

mikemanookin, 2025-03-30:
I have whole-cell recordings of excitatory and inhibitory synaptic inputs to individual neurons and I would like to inject those conductances in dynamic clamp. Is it possible to pass in excitatory and inhibitory conductances separately with your device? It seems like there is only one input for conductances unless I'm not understanding something... which is totally possible. Thank you!

nsdesai, 2025-03-30:
Hi Mike,

It is possible to feed two (or more) conductances into the dynamic clamp system.
Shortly after the eNeuro paper was published, I tried doing that in response to a question from someone in a retina lab. It worked. I took excitatory and inhibitory conductances measured  in vivo from a mouse M2 neuron and fed them into a similar neuron in the much more tractable environs of a brain slice. You can read a writeup of the issues involved here:

https://optogeneticsandneuralengineeringcore.gitlab.io/dynamicclampsitetwo/externalorsavedconductances/

and see the code itself here:

https://github.com/nsdesai/dynamic_clamp/tree/master/external_conductances

However, I don’t actually recommend you use this code for two reasons. First, PJRC no longer sells the Teensy 3.6. Instead, people have recently turned to a similar microcontroller from Adafruit: https://www.adafruit.com/product/3800. It has the same chip as the Teensy 3.6 and almost identical specifications, but its form factor is smaller and the pin assignments are different. Second, I realized, in response to a question from somebody else, that I had made the code way more complicated then it needed to be. Just using the simple analogRead() function three times in a row (to measure Vm, excitatory conductance, and inhibitory conductance) doesn’t slow things down that much. You can still get at least 50 kHz performance, which for most use cases is fine.

Let me know if you’re interested in building your own dynamic clamp system. There are a few options to consider: a really nice PCB version designed by Leo and Manuel Covarrubias, a breadboard version less messy than the original designed by me, various software implementations.

Best wishes,

Niraj

mikemanookin, 2025-03-30:
Thank you Niraj!

Yes, I would be interested in building my own system. I will try anything, but I generally would prefer a PCB system if it's capable of feeding two or more external conductances in. Any help you could give would be greatly appreciated. Is the PCB version the one in this repo (./open-dynamic-clamp/ocd-1.2)?

Thank you!

Mike

nsdesai, 2025-03-30:
Hi Mike,

Yes, the PCB version I referred to is the Open Dynamic Clamp 1.2, which is described here:

https://github.com/nsdesai/dynamic_clamp/tree/master/open-dynamic-clamp/odc-1.2

It was designed and built by Leo Covarrubias. It improves upon the breadboard design in several ways: it is built on a rugged PCB rather than a fragile breadboard, it draws power from the USB connector itself rather than requiring a separate power source, it gives easy access to the microcontroller’s reset button and a way to switch the dynamic clamp system into and out of the amplifier’s path, and it has an enclosure with a nifty logo.  I’ve tried it out myself and it is excellent.

What it doesn’t have, compared to a breadboard, is an easy way to change the connections. The ItsyBitsy M4 microcontroller has multiple I/O inputs that can serve as ADC inputs. But, in Leo’s present PCB design, only one is accessible (the one that reads membrane potential). So, we need to get access to two more of the inputs.

That should be totally doable. I don’t actually know to do it – because I am a humble biologist ¯\_(ツ)_/¯  –  but I expect it would be easy for Leo. I will ask him. Or if you know how to do it, by all means – this is an open source project after all, everybody can contribute.

Best,

Niraj

mikemanookin, 2025-03-30:
I am also a humble biologist :), so if you wouldn't mind asking Leo, I would really appreciate it. Thanks so much!

nsdesai, 2025-03-30:
I will ask Leo. I am sure he will help.

The way he got involved in the project was through his father, Manuel Covarrubias, who is a professor at Thomas Jefferson medical school. [https://research.jefferson.edu/labs/researcher/covarrubias-laboratory.html](url) Manuel’s lab studies potassium channels in neurons and heart cells, and one of his students, Tyler Alexander, used this system in a recent study of DRG neurons ([Alexander et al. 2024](https://www.pnas.org/doi/10.1073/pnas.2411033121)). Manuel’s engineer son Leo heard of the project from his Dad and thought “I can make this better.” And he did! I like Leo’s design a lot – clean and compact.
Leo’s been generous with his time, and I expect he will be again.

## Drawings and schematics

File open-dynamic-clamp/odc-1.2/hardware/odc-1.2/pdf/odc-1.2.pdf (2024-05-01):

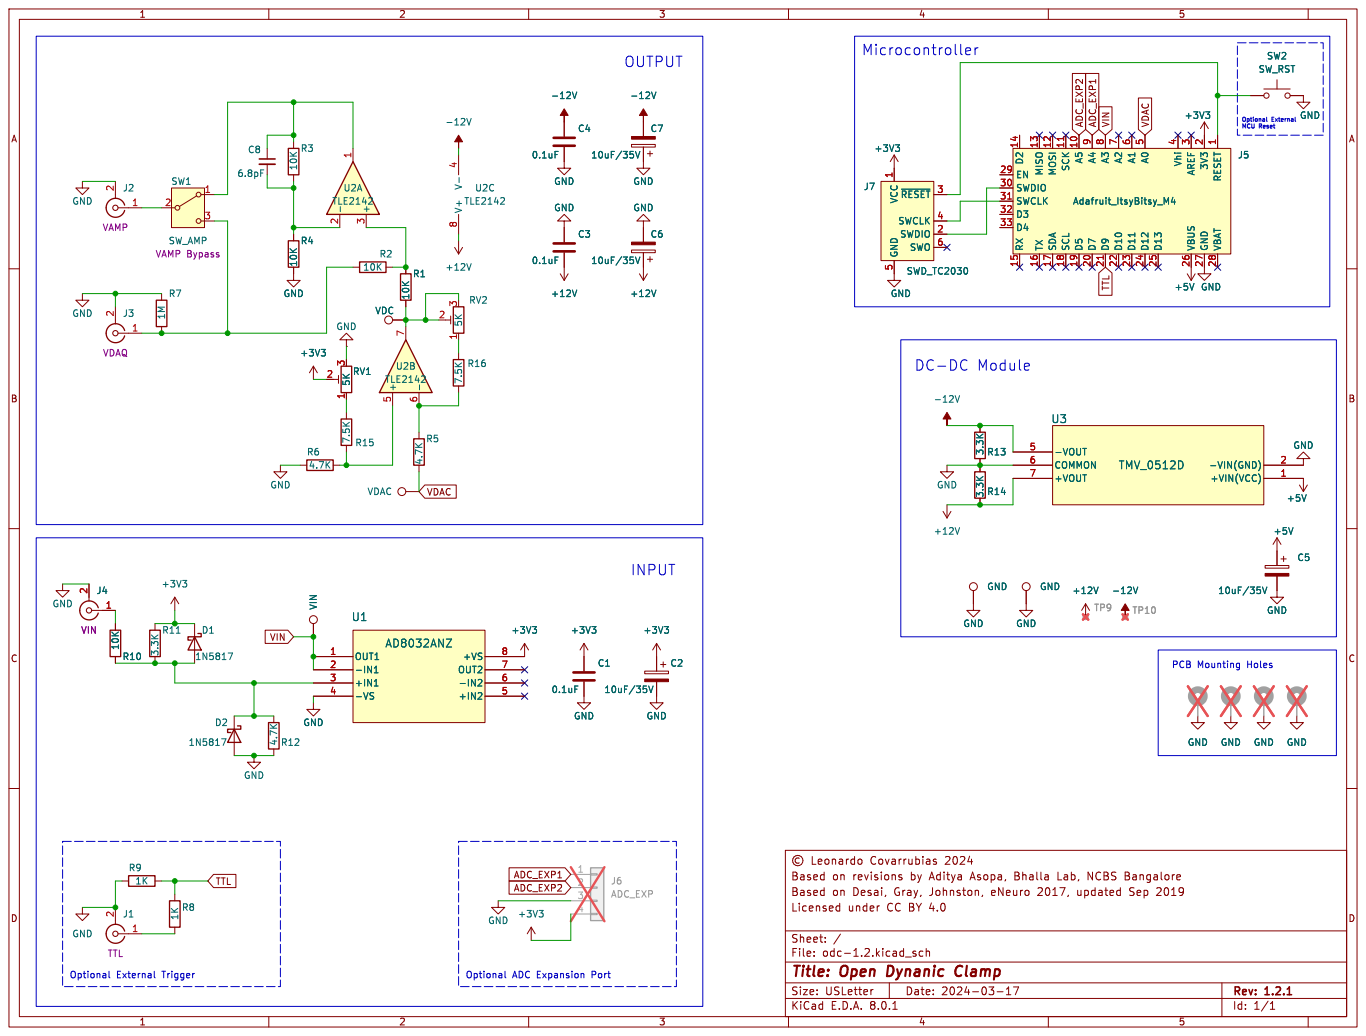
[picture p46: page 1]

1 A5 10 SCK 11 MOSI 12 MISO 13 D2 14 RX 15 TX 16 SDA 17 SCL 18 D5 19 3V3

2 D7 20 D9 21 D10 22 D11 23 D12 24 D13 25 VBUS 26 GND 27 VBAT 28 EN 29 AREF

1 SWDIO 2 ~{RESET}3 SWCLK 4 GND

Id: 1/1 Title: Open Dynanic Clamp

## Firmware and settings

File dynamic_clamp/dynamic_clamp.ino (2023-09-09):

// Arduino sketch to implement dynamic clamp
//
// The sketch includes a main file (this one) and other files (which appear as tabs) that define the conductances.
// The main file is organized like this:
//      (i)   global variables are declared first. gain_INPUT and gain_OUTPUT are properties of the patch
//            clamp amplifier (a user should specify these for their own amplifier). The calibration parameters
//            are properties of the components on the breadboard (and are usually set by the calibration sketch).
//            The dynamic clamp parameters will be specified by the Processing GUI or by some other program (Matlab,
//            Igor Pro, Python, etc.) the user chooses. dt and t0 are used to keep time. Hardware connections
//            are chosen by the user.
//      (ii)  setup(). Every Arduino-like sketch includes a setup() function which is run when the sketch is 
//            uploaded to the microcontroller. Serial communication is established with the host computer (for use
//            by Processing, Matlab, Igor Pro, Python, or whatever). 12-bit resolution is specified for analog
//            read and write. Any numbers that should be pre-calculated and stored in global variables (e.g.,
//            the lookup table numbers for sodium activation/inactivation) are calculated by calling the function
//            (in one of the tabbed files) that defines them. The trigger pin for EPSCs is established.
//      (iii) loop(). The loop() function is run continuously (i.e., once per time step). The first part checks
//            whether the microcontroller has received any serial communication instructing it to change the
//            dynamic clamp parameters (e.g., shunt conductance or OU excitatory diffusion constant). The second 
//            part reads the signal from the patch clamp amplifier's output (which has already been buffered,
//            shifted, and scaled by the breadboard electronics), converts this signal into membrane potential v
//            in millivolts (using the calibration parameters), and sends v out to the functions (in the tabbed files)
//            that calculate the dynamic clamp current in picoamps for the various conductances. All of these currents
//            are summed. The third and last part converts the summed current (in picoamps) into the output to 
//            be sent (0-4095) from the analog output pin. This output will be shifted, scaled, and added to the 
//            DAQ board's current clamp command by breadboard electronics. The total signal will then be fed to 
//            the patch clamp amplifier's command input. 
// Each dynamic clamp conductance is defined by one of the tabbed files. These files can contain multiple functions
//            and their own global variables (accessible to the functions of the tabbed file). For example, the file Sodium
//            contains declarations for the activation/inactivation lookup variables, a function that calculates the activation
//            and inactivation numbers for a range of membrane potentials and stores them in the lookup table variables,
//            and the function called at every time step to calculate the sodium current to be injected. 
//


#include <math.h>

#if defined(TEENSYDUINO)
    // => running on teensy 3.6
    #define DIGITAL_READ(pin) digitalReadFast(pin)
    #define SEND_NOW() Serial.send_now()
    // ADC pin used to read membrane potential
    #define PIN_ANALOG_IN 0
    // DAC pin used to output current
    #define PIN_ANALOG_OUT A21
    // pin used to trigger EPSC train
    #define PIN_EPSC_TRIGGER 2

#elif defined(ADAFRUIT_ITSYBITSY_M4_EXPRESS)
    // => running on adafruit itsybitsy m4
    // `elapsedMillis` library is a required dependency
    #include <elapsedMillis.h>
    #define DIGITAL_READ(pin) digitalRead(pin)
    #define SEND_NOW() Serial.flush()
    // ADC pin used to read membrane potential
    #define PIN_ANALOG_IN A3
    // DAC pin used to output current
    #define PIN_ANALOG_OUT DAC0
    // pin used to trigger EPSC train
    #define PIN_EPSC_TRIGGER 7

#else
    // => running on some other board
    // `elapsedMillis` library is a required dependency
    #include <elapsedMillis.h>
    #define DIGITAL_READ(pin) digitalRead(pin)
    #define SEND_NOW() Serial.flush()
    // ADC pin used to read membrane potential
    #define PIN_ANALOG_IN A1
    // DAC pin used to output current
    #define PIN_ANALOG_OUT DAC0
    // pin used to trigger EPSC train
    #define PIN_EPSC_TRIGGER 5
#endif


// Scaling for the patch clamp amplifier
const float gain_INPUT = 100.0;                   // number of millivolts sent out by amplifier for each millivolt of membrane potential
                                                  // e.g., with a scaling of 50, if the membrane potential is -65 mV, the amplifier outputs -3.25 V
const float gain_OUTPUT = 400.0;                  // number of picoamps injected for every volt at the amplifier's command input
                                                  // e.g., if the DAC or the Teensy outputs -0.5 V, this is interpreted as -200 pA by the amplifier
                                                  // when the scaling is 400


// Calibrating the input/output numbers given the resistor values and power supply values of the breadboard
// n.b., these parameters (numerators) are properties of the components on the breadboard;
// they are independent of the amplifier and DAQ board
const float inputSlope = 5.0375 / gain_INPUT;
const float inputIntercept = -10312.50 / gain_INPUT;
const float outputSlope = -583.3586 / gain_OUTPUT;
const float outputIntercept = 1925.0834;

// Conductance parameters are sent by the host computer over the USB port
const int nPars = 8;              // number of adjustable parameters
float gShunt = 0.0;               // nS, shunting conductance
float gH = 0.0;                   // nS, maximal H (HCN) conductance
float gNa = 0.0;                  // nS, maximal fast, transient sodium conductance
float OU1_mean = 0.0;             // nS, excitatory Ornstein-Uhlenbeck (OU) mean conductance
float OU1_D = 0.0;                // nS^2/msec, excitatory OU diffusion constant
float OU2_mean = 0.0;             // nS, inhibitory OU mean conductance
float OU2_D = 0.0;                // nS^2/msec, inhibitory OU diffusion constant
float gEPSC = 0.0;                // nS, maximal conductance of EPSCs

// Common global variables
float dt = 0.01;                  // msec, the time step -- on a Teensy/Arduino dt will be variable
elapsedMicros t0;                 // microsec, t0 is used to calculate dt on every iteration
elapsedMillis epscTime;           // msec, time since last EPSC was triggered

// Timing parameters for serial port communication
const int pollInterval = 100;     // msec, polling interval for serial port communication
elapsedMillis p0 = 0;             // msec, time since last polling interval ended


void setup() {
  Serial.begin(115200);
  analogWriteResolution(12);
  analogReadResolution(12);
  while (Serial.available()>0) {                // make sure serial buffer is clear
    Serial.read();
  }
  GenerateGaussianNumbers();                    // generate a pool of Gaussian numbers for use by the OU processes
  GenerateSodiumLUT();                          // generate sodium activation/inactivation lookup table
  GenerateHcnLUT();                             // generate HCN activation lookup table
  pinMode(PIN_EPSC_TRIGGER, INPUT);             // define the pin that receives a trigger when an EPSC should be injected
}

// vars to decode params sent from GUI
float dataTemp[nPars] = {0.00};
int parNo = 0;
float tempVal;
char tempBytes[4];

void loop() {
    // Part 1:    Serial Communication & Parameter Setting
    // The host computer tells the Teensy when the dynamic clamp parameters should change.
    // To do this, it sends 4-byte-long numbers, one for each parameter. So if there are
    // 8 adjustable parameters, it will send 32 bytes. At present, the adjustable parameters
    // are the shunt conductance (nS), maximal HCN conductance (nS), maximal Na conductance (nS),
    // excitatory OU conductance (OU1) mean (nS), excitatory OU conductance diffusion constant (nS^2/ms),
    // inhibitory OU conductance (OU2) mean (nS), inhibitory OU conductance (OU2) diffusion
    // constant (nS^2/ms), and maximal EPSC conductance (nS).
    if (p0 > pollInterval) {

        while (Serial.available()) {
            Serial.readBytes(tempBytes, 4);
            memcpy(&tempVal, &tempBytes, 4);
            dataTemp[parNo] = tempVal;
            parNo++;
        }

        if (parNo == nPars) {
            gShunt = dataTemp[0];
            gH = dataTemp[1];
            gNa = dataTemp[2];
            OU1_mean = dataTemp[3];
            OU1_D = dataTemp[4];
            OU2_mean = dataTemp[5];
            OU2_D = dataTemp[6];
            gEPSC = dataTemp[7];

            for (int n = 0; n < nPars; n++) {
                Serial.println(dataTemp[n], 6);
                SEND_NOW();
            }
            parNo = 0;
        }
        p0 = 0;
    }

    // Part 2:    Read membrane potential & calculate dynamic clamp currents
    float v = inputSlope * analogRead(PIN_ANALOG_IN) + inputIntercept;    // mV, given amplifier settings
    float injectionCurrent = 0.0;                                       // pA
    dt = 0.001 * (float) t0;                                               // msec, time step
    t0 = 0;                                                             // set elapsed time back to zero

    if (gShunt > 0) {
        injectionCurrent += Shunting(v);
    }

    injectionCurrent += HCN(v, gH);                                     // allows for the reset of a current after its initial run

    if (gNa > 0) {
        injectionCurrent += Sodium(v);
    }
    if (OU1_mean > 0 || OU2_mean > 0) {
        injectionCurrent += OrnsteinUhlenbeck(v);
    }
    if (gEPSC > 0) {
        if ((DIGITAL_READ(PIN_EPSC_TRIGGER) == HIGH) && (epscTime > 2)) {      // poll epscTriggerPin to see if a trigger has arrived
            UpdateEpscTrain();
            epscTime = 0;
        }
        injectionCurrent += EPSC(v);
    }


    // Part 3:      Send out the calculated dynamic clamp current
    injectionCurrent = outputSlope * injectionCurrent + outputIntercept;  // pA converted into analog output integers
    int outputSignal = constrain((int) injectionCurrent, 0, 4095);           // make sure the output is an integer between 0 and 4095 (12 bits)
    analogWrite(PIN_ANALOG_OUT, outputSignal);                               // send the output to the patch clamp or summing amplifier
}

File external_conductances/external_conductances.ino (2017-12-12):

// Dynamic clamp sketch when using externally-generated conductances.
//
// This sketch monitors four of the Teensy microcontroller's analog inputs. One of these reads the membrane potential (Vm); the other
// three can be used to read conductance signals sent out by the DAQ board (or by some other source). The Teensy will multiply
// each conductance by its associated driving force (difference between Vm and the conductance's reversal potential, Erev) to
// get the current through that conductance. It will then sum all the currents and send the sum through the DAC output.
// 
// The typical use case would be feeding excitatory and inhibitory conductance trains into a neuron to simulate "in vivo-like"
// conditions. The trains may, for example, have been derived from voltage clamp recordings or from a network simulation.
// 
// Before uploading this sketch, users should change the parameters at the top.
// (A) The input/output gains, slopes, and intercepts should be the same as for the original dynamic clamp sketch. The gains
//     are set by the patch clamp amplifier. The slopes and intercepts should be set using the protocol described in www.dynamicclamp.com
//     (see "Calibration"). 
// (B) sampleFrequency should be set to 10000, 20000, 25000, 40000, 50000, or 100000 Hz.
// (C) channelsInUse should be set, as should the associated reversal potentials and the scaling factors. The scaling
//     factor (nS/V) for a given analog input indicates how a voltage (0-3.3 V) received by that input should be converted
//     into a conductance (in nS).  
//
// This sketch makes use of Pedro Villaneuva's ADC library for the Teensy (https://github.com/pedvide/ADC) and a sketch for 
// sampling four ADC channels more-or-less simultaneously contributed by PJRC.com forum senior member "tni" (whose real name
// I do not know). The latter sketch can be found at
// https://forum.pjrc.com/threads/45206-Pedvide-s-ADC-library-multiple-channel-simultaneous-amp-continuous-acquisition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
// And, of course, no part of this project would be possible without Paul Stoffregen's introduction of and work on the Teensy.
//
// Last updated December 11, 2017 (NSD)


#include <ADC.h>
#include <array>


// Scaling for the patch clamp amplifier
const float gain_INPUT = 50.0;                    // number of millivolts sent out by amplifier for each millivolt of membrane potential
                                                  // e.g., with a scaling of 50, if the membrane potential is -65 mV, the amplifier outputs -3.25 V
const float gain_OUTPUT = 400.0;                  // number of picoamps injected for every volt at the amplifier's command input
                                                  // e.g., if the DAC or the Teensy outputs -0.5 V, this is interpreted as -200 pA by the amplifier
                                                  // when the scaling is 400


// Calibrating the input/output numbers given the resistor values and power supply values of the breadboard
// n.b., these parameters (numerators) are properties of the components on the breadboard;
// they are independent of the amplifier and DAQ board
const float inputSlope = 5.4084/gain_INPUT;      
const float inputIntercept = -11061.9349/gain_INPUT;    
const float outputSlope = 753/gain_OUTPUT;       
const float outputIntercept = 2386;


const int sampleFrequency = 100000;   // Hz (choose one: 10000, 20000, 25000, 40000, 50000, or 100000)
const bool  channelsInUse[3] = {true,true,false};   // the default, [true,true,false], means two conductance trains (e.g., excitation and inhibition) 
const float reversalPotentials[3] = {0.0,-80.0, 0.0};   // reversal potentials for channels (e.g., 0 mV for excitation, -80 mV for inhibition)
const float scalingFactors[3] = {10.0, 10.0, 1.0};    // scaling factors (nS/V)


// We adjust the time step (dt) and the number of averages the analog inputs take before reporting a measurement (nAverages) based on
// the desired sampleFrequency.
int dt = int(1E6/sampleFrequency);
int nAverages = int(100000/sampleFrequency);


// pin assignments: Teensy 3.6 has two hardware ADC channels (ADC0 and ADC1); these are multiplexed to give 25 total analog inputs.
// We use one (A0) to read Vm. The others (A1, A12, A13) can read conductance trains; these are the first, second, and third elements of
// channelsInUse, reversalPotentials, and scalingFactors as defined above.
const uint8_t adc0_pin0 = A0;     // ADC0
const uint8_t adc0_pin1 = A1;     // ADC0
const uint8_t adc1_pin0 = A12;    // ADC1
const uint8_t adc1_pin1 = A13;    // ADC1
const int dac_pin0 = A21;         // DAC0


float prefactors[3];   // will be used in loop() to scale currents correctly


constexpr std::array<uint8_t, 4> adc_pins = { adc0_pin0, adc0_pin1, adc1_pin0, adc1_pin1 };

ADC adc;
std::array<ADC_Module*, 2> adc_modules;
static_assert(ADC_NUM_ADCS == 2, "Two ADCs expected.");


struct Measurement {
    std::array<volatile uint16_t, 4> v;
};

std::array<Measurement, 100> buffer;
volatile size_t write_pos = 0;

// CMSIS PDB
#define PDB_C1_EN_MASK                           0xFFu
#define PDB_C1_EN_SHIFT                          0
#define PDB_C1_EN(x)                             (((uint32_t)(((uint32_t)(x))<<PDB_C1_EN_SHIFT))&PDB_C1_EN_MASK)
#define PDB_C1_TOS_MASK                          0xFF00u
#define PDB_C1_TOS_SHIFT                         8
#define PDB_C1_TOS(x)                            (((uint32_t)(((uint32_t)(x))<<PDB_C1_TOS_SHIFT))&PDB_C1_TOS_MASK)
#define PDB_C1_BB_MASK                           0xFF0000u
#define PDB_C1_BB_SHIFT                          16
#define PDB_C1_BB(x)                             (((uint32_t)(((uint32_t)(x))<<PDB_C1_BB_SHIFT))&PDB_C1_BB_MASK)
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

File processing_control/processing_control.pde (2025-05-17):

// This Processing sketch opens a GUI in which users can specify the
// conductance parameters used by the Teensy microcontroller.
//
// There are eight of them at present:
//     - shunt conductance (g_shunt, nS)
//     - maximum HCN conductance (g_hcn, nS)
//     - maximum sodium conductance (g_Na, nS)
//     - mean excitatory Ornstein-Uhlenbeck conductance (m_OU_exc, nS)
//     - diffusion constant of excitatory Ornstein-Uhlenbeck conductance (D_OU_exc, nS^2/ms)
//     - mean inhibitory Ornstein-Uhlenbeck conductance (m_OU_inh, nS)
//     - diffusion constant of inhibitory Ornstein-Uhlenbeck conductance (D_OU_inh, nS^2/ms)
//     - maximum EPSC conductance (g_epsc, nS)
//
// The numbers can be adjusted using the sliders.
//
// Pressing "connect" will connect to the microcontroller via the serial port.
// Pressing "upload" will send the numbers in the GUI to the microcontroller.
// Pressing "zero" will set all the numbers to zero and send zeros to the microcontroller.
//
// The sketch requires the ControlP5 library.
//

import controlP5.*;
import processing.serial.Serial;
import java.text.*;
import java.io.*;
import java.nio.*;

// ---
// a serial object (the port to communicate with the microcontroller)
// change port if needed in the UI
String DEFAULT_SERIAL_PORT = System.getProperty("os.name").startsWith("Windows")
  ? " COM3"                    // usual windows default
  : " /dev/cu.usbmodem101";    // usual posix default
Serial mcuPort;

// ---
// define variables for the ControlP5 object (the GUI)
ControlP5 cp5;

color textColor = color(100, 100, 100);
color inputColor = color(64, 64, 64);
color disabledColor = color(200, 200, 200);
color buttonColor = color(0, 45, 95);
color okColor = color(64, 200, 64);
color failColor = color(200, 64, 64);

Button connectButton;
Button uploadButton;
Button zeroButton;
Textfield connectTextfield;
Textfield g_epsc_textfield;

// ---
// storage vars
String[] echo = new String[8];

// initialize the variables set by the GUI
float g_shunt = 0;
float g_hcn = 0;
float g_Na = 0;
float m_OU_exc = 0;
float D_OU_exc = 0;
float m_OU_inh = 0;
float D_OU_inh = 0;


void setup() {
  int offsetX = 100;
  int offsetY = 50;

  // specify GUI window size, color, and text case
  size(450, 650);
  Label.setUpperCaseDefault(false);

  // create the ControlP5 object, add sliders, specify the font, and add buttons
  cp5 = new ControlP5(this);

  PFont pfont = createFont("Arial", 8, true);
  ControlFont font = new ControlFont(pfont, 18);
  cp5.setFont(font);

  connectTextfield = cp5.addTextfield("Serial Port", offsetX, offsetY, 200, 30)
    .setText(DEFAULT_SERIAL_PORT)
    .setColorBackground(inputColor);
  connectButton = cp5.addButton("connect");
  connectButton.setPosition(offsetX + 220, offsetY)
    .setSize(80, 30)
    .setColorBackground(buttonColor)
    .setColorForeground(textColor);

  offsetY+=75;
  cp5.addSlider("g_shunt", 0, 10, 0, offsetX, offsetY, 200, 30)
    .setColorBackground(inputColor);
  offsetY+=50;
  cp5.addSlider("g_hcn", 0, 10, 0, offsetX, offsetY, 200, 30)
    .setColorBackground(inputColor);
  offsetY+=50;
  cp5.addSlider("g_Na", 0, 200, 0, offsetX, offsetY, 200, 30)
    .setColorBackground(inputColor);
  offsetY+=50;
  cp5.addSlider("m_OU_exc", 0, 10, 0, offsetX, offsetY, 200, 30)
    .setColorBackground(inputColor);
  offsetY+=50;
  cp5.addSlider("D_OU_exc", 0, 10, 0, offsetX, offsetY, 200, 30)
    .setColorBackground(inputColor);
  offsetY+=50;
  cp5.addSlider("m_OU_inh", 0, 10, 0, offsetX, offsetY, 200, 30)
    .setColorBackground(inputColor);
  offsetY+=50;
  cp5.addSlider("D_OU_inh", 0, 10, 0, offsetX, offsetY, 200, 30)
    .setColorBackground(inputColor);
  offsetY+=50;
  g_epsc_textfield = cp5.addTextfield("g_epsc", offsetX, offsetY, 200, 30)
    .setText(" 0.00")
    .setColorBackground(inputColor);

  offsetY+=75;

  uploadButton = cp5.addButton("upload");
  uploadButton.setPosition(offsetX+25, offsetY)
    .setSize(80, 50)
    .setColorBackground(disabledColor)
    .setColorForeground(textColor)
    .setLock(true);

  zeroButton = cp5.addButton("zero");
  zeroButton.setPosition(offsetX+150, offsetY)
    .setSize(80, 50)
    .setColorBackground(disabledColor)
    .setColorForeground(textColor)
    .setLock(true);
    
}


void draw() {
  // draw a background so fonts are antialiased
  background(color(150, 150, 150));
}


// connect to desired com port
void connect() {
  println("connecting...");

  // create the serial port used to communicate with the microcontroller
  try {
    mcuPort = new Serial(this, connectTextfield.getText().trim(), 115200);
  }
  catch(Exception e) {
    println("connect to serial port failed");
    connectTextfield.setColorBackground(failColor);
    uploadButton.setColorBackground(disabledColor).setLock(true);
    zeroButton.setColorBackground(disabledColor).setLock(true);
    return;
  }
  mcuPort.clear();

  connectTextfield.setColorBackground(okColor);
  uploadButton.setColorBackground(textColor).setLock(false);
  zeroButton.setColorBackground(textColor).setLock(false);

  println("connected!");
}


boolean isConnected() {
  return mcuPort != null;
}


// Upload the numbers in the GUI to the microcontroller.
void upload() {
  if (! isConnected()) {
    return;
  }

  print("Updating ...");
  writeToMcu(g_shunt);
  writeToMcu(g_hcn);
  writeToMcu(g_Na);
  writeToMcu(m_OU_exc);
  writeToMcu(D_OU_exc);
  writeToMcu(m_OU_inh);
  writeToMcu(D_OU_inh);
  writeToMcu(Float.parseFloat(g_epsc_textfield.getText()));

  println(" response from MCU:");
  if (confirmed()) {         // conductance values shown in GUI and interpreted by Teensy are identical
    cp5.getController("upload").setColorForeground(okColor);
  } else {                   // conductance values differ: rounding artifacts or transmission errors
    cp5.getController("upload").setColorForeground(failColor);
  }
}



// Zero all the numbers in the GUI and transmit zeros to the microcontroller.
void zero() {
  if (! isConnected()) {
    return;
  }

  cp5.getController("g_shunt").setValue(0.0);
  cp5.getController("g_hcn").setValue(0.0);
  cp5.getController("g_Na").setValue(0.0);
  cp5.getController("m_OU_exc").setValue(0.0);
  cp5.getController("D_OU_exc").setValue(0.0);
  cp5.getController("m_OU_inh").setValue(0.0);
  cp5.getController("D_OU_inh").setValue(0.0);
  g_epsc_textfield.setText(" 0.00");

  upload();
}
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

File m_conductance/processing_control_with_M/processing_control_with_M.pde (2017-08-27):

// This Processing sketch opens a GUI in which users can specify the
// conductance parameters used by the Teensy microcontroller. There are eight of 
// them at present: shunt conductance (g_shunt, nS), maximum HCN conductance (g_hcn, nS),
// maximum sodium conductance (g_Na, nS), mean excitatory Ornstein-Uhlenbeck
// conductance (m_OU_exc, nS), diffusion constant of excitatory Ornstein-Uhlenbeck
// conductance (D_OU_exc, nS^2/ms), mean inhibitory Ornstein-Uhlenbeck conductance
// (m_OU_inh, nS), diffusion constant of inhibitory Ornstein-Uhlenbeck conductance
// (D_OU_inh, nS^2/ms), maximum EPSC conductance (g_epsc, nS), and maximum M
// conductance (g_M, nS).
//
// The numbers can be adjusted using the sliders.
//
// Pressing "upload" will send the numbers in the GUI to the microcontroller.
// Pressing "zero" will set all the numbers to zero and send zeros to the microcontroller.
//
// The sketch requires the ControlP5 library.
//
// PROCESSING CONTROL WITH M


// import libraries
import controlP5.*;
import processing.serial.*;
import java.text.*;
import java.io.*;
import java.nio.*;

// define variables for the ControlP5 object (the GUI) and 
// a serial object (the port to communicate with the microcontroller)
ControlP5 dcControl;
Serial myPort;

// initialize the variables set by the GUI
float g_shunt = 0;
float g_hcn = 0;
float g_Na = 0;
float m_OU_exc = 0;
float D_OU_exc = 0;
float m_OU_inh = 0;
float D_OU_inh = 0;
float g_epsc = 0;
float g_M = 0;


void setup() {
  
    // specify GUI window size, color, and text case
    size(450,600);
    background(150);
    Label.setUpperCaseDefault(false);
    
    // create the ControlP5 object, add sliders, specify the font, and add buttons
    dcControl = new ControlP5(this);
    dcControl.addSlider("g_shunt", 0, 10, 0, 100, 50, 200, 30);
    dcControl.addSlider("g_hcn", 0, 10, 0, 100, 100, 200, 30);
    dcControl.addSlider("g_Na", 0, 200, 0, 100, 150, 200, 30);
    dcControl.addSlider("m_OU_exc", 0, 10, 0, 100, 200, 200, 30);
    dcControl.addSlider("D_OU_exc", 0, 10, 0, 100, 250, 200, 30);
    dcControl.addSlider("m_OU_inh", 0, 10, 0, 100, 300, 200, 30);
    dcControl.addSlider("D_OU_inh", 0, 10, 0, 100, 350, 200, 30);
    dcControl.addSlider("g_epsc", 0, 10, 0, 100, 400, 200, 30);
    dcControl.addSlider("g_M", 0, 10, 0, 100, 450, 200, 30);
    PFont pfont = createFont("Arial", 8, true);
    ControlFont font = new ControlFont(pfont, 18);
    dcControl.setFont(font);
    dcControl.addBang("upload").setPosition(125,500).setSize(60,50).setColorForeground(color(100,100,100));
    dcControl.addBang("zero").setPosition(250,500).setSize(60,50).setColorForeground(color(100,100,100));
    
    // create the serial port used to communicate with the microcontroller
    myPort = new Serial(this,"COM7",115200);
    myPort.clear();
    
}



void draw(){
  // nothing to see here: the Processing language requires every sketch to contain a draw() function
}


// Upload the numbers in the GUI to the microcontroller.
void upload(){
      writetoteensy(g_shunt);
      writetoteensy(g_hcn);
      writetoteensy(g_Na);
      writetoteensy(m_OU_exc);
      writetoteensy(D_OU_exc);
      writetoteensy(m_OU_inh);
      writetoteensy(D_OU_inh);
      writetoteensy(g_epsc);
      writetoteensy(g_M);
}



// Zero all the numbers in the GUI and transmit zeros to the microcontroller.
void zero(){
    dcControl.getController("g_shunt").setValue(0.0);
    dcControl.getController("g_hcn").setValue(0.0);
    dcControl.getController("g_Na").setValue(0.0);
    dcControl.getController("m_OU_exc").setValue(0.0);
    dcControl.getController("D_OU_exc").setValue(0.0);
    dcControl.getController("m_OU_inh").setValue(0.0);
    dcControl.getController("D_OU_inh").setValue(0.0);
    dcControl.getController("g_epsc").setValue(0.0);
    dcControl.getController("g_M").setValue(0.0);
    upload();
}



// The numbers from the GUI (floats) are converted to unsigned bytes
// and written to the Teensy.
void writetoteensy(float foo) {    
    byte[] b;
    ByteBuffer byteBuffer = ByteBuffer.allocate(4);
    byteBuffer.order(ByteOrder.LITTLE_ENDIAN);
    b = byteBuffer.putFloat(foo).array();
    for (int y=0; y<4; y++) {    // This is probably not necessary
      int boo = (b[y]&0xFF);     // since negative bytes get converted
      myPort.write(boo);         // when written
    }
}


// dispose() is invoked when the applet window closes.
// It just cleans everything up.
void dispose() {
    myPort.clear();
    myPort.stop();
    println("Stopping ...");
}  

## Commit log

2018-02-16 Average analog input and send it to the terminal.
    Average the analog input to reduce impact of high-frequency noise, before sending it to the analog output. In addition, send the digital representation of the averaged analog input to the terminal - which can be used for a manual calibration of the analog input.
    [passthrough.ino]
2018-02-16 Echo input value to terminal
    In addition to creating the output current, send the digital input value to the terminal - so that the user can verify the input.
2018-05-15 Serial port timer added, HCN current reset added
    * The serial port is now checked frequently (100 ms) for conductance changes from the users, freeing CPU ressources for purposes.
    * The activation gate for the HCN current will now properly reset, when the conductance is reset to zero - i.e. when repeating sequences with different conductance values (experiments) and conductance values of zero (controls)
    [HCN.ino, dynamic_clamp.ino]
2018-05-21 Serial port echo added
    * Teensy now returns the conductance values after retrieval - this can be used to validate the transmission
2018-05-21 Transmission validation added
    * Processing now interprets the Teensy's serial port echo to validate the data transmission
    * The GUI now colors individual conductance values and the upload button depending on transmission success (green = success, red = fail)
    * The slider for "g_epsc" was replaced by a text field in order to serve as a GUI template
    [processing_control.pde]
2018-05-21 port updated
    * Port COM3 is the default port for newly added devices
2020-09-09 Added circuit version 2.0 schematic and gerbers
    Following up the September 2019 update to the circuit (https://onedrive.live.com/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)
    I made the circuit using KiCAD with following two additions:
    1. Added a power LED between +6V rail and GND.
    2. Added a set of breakout pins from Teensy onto the board. These pins are: GND, DAC1, RX1, TX1, SCL0, SDA0, A5-A9.
    [teenDynClamp_V02-B_Cu.gbl, teenDynClamp_V02-B_Mask.gbs, teenDynClamp_V02-B_SilkS.gbo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]
2020-09-09 Revert "Added circuit version 2.0 schematic and gerbers"
    This reverts commit ff1f8ee5672fe21bc114cbd84262375fa3e0d3b0.
    [teenDynClamp_V02-B_Cu.gbl, teenDynClamp_V02-B_Mask.gbs, teenDynClamp_V02-B_SilkS.gbo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]
2020-09-09 Added Circuit Schematic and PCB layout
    As per the September 2019 update by Niraj.(https://onedrive.live.com/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)
    Also added:
    1. Breakout pins from Teensy A4-A9, GND, SCL0, SDA0, TX1, RS1.
    2. Power LED
    CC BY 4.0
    [teenDynClamp_V02-B_Cu.gbl, teenDynClamp_V02-B_Mask.gbs, teenDynClamp_V02-B_SilkS.gbo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]
2020-09-10 Added Mode toggle and TTL Safety
    As suggested by Niraj, added two more features to the design:
    1. A 0.5x voltage divider to protect teensy from TTL voltages above 3.3V.
    2. Added a toggle switch which can either bypass the dynamic clamp. Switch footprint is of a pin-header where any dual pole dual throw switch can be soldered. There are indicator LEDs to show which m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
    [teenDynClamp_V02-B_Cu.gbl, teenDynClamp_V02-B_Mask.gbs, teenDynClamp_V02-B_SilkS.gbo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]
2020-09-10 deleted old gerbers
2020-09-10 Added pulldown resistor
    [teenDynClamp_V02-B_Cu.gbl, teenDynClamp_V02-B_Mask.gbs, teenDynClamp_V02-B_SilkS.gbo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]
2021-07-16 Added a manual for board setup and calibration.
    with detailed description, theoretical, and empirical measurements of input and output relationships for the board.
2023-09-09 refactor: update ino for samd51 (itsybitsy m4), fix processing control
    [dynamic_clamp.ino, processing_control.pde]
2024-05-01 feat: complete hardware 1.2.1
    [000-46650-75rfx.igs, 14-Pin Header - Male - 2.54mm.step, 3800-ItsyBitsy-M4.step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]
2024-05-01 corrected typo
    [000-46650-75rfx.igs, 14-Pin Header - Male - 2.54mm.step, 3800-ItsyBitsy-M4.step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]
2024-06-14 feat: export soldermask gbr, extra gitignore
    [odc-1.2-B_Cu.gbr, odc-1.2-B_Mask.gbr, odc-1.2-Edge_Cuts.gbr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]
2024-09-21 fix: corrections to odc 1.2 calibration values and spreadsheet
2025-05-17 fixed case-sensitive error
